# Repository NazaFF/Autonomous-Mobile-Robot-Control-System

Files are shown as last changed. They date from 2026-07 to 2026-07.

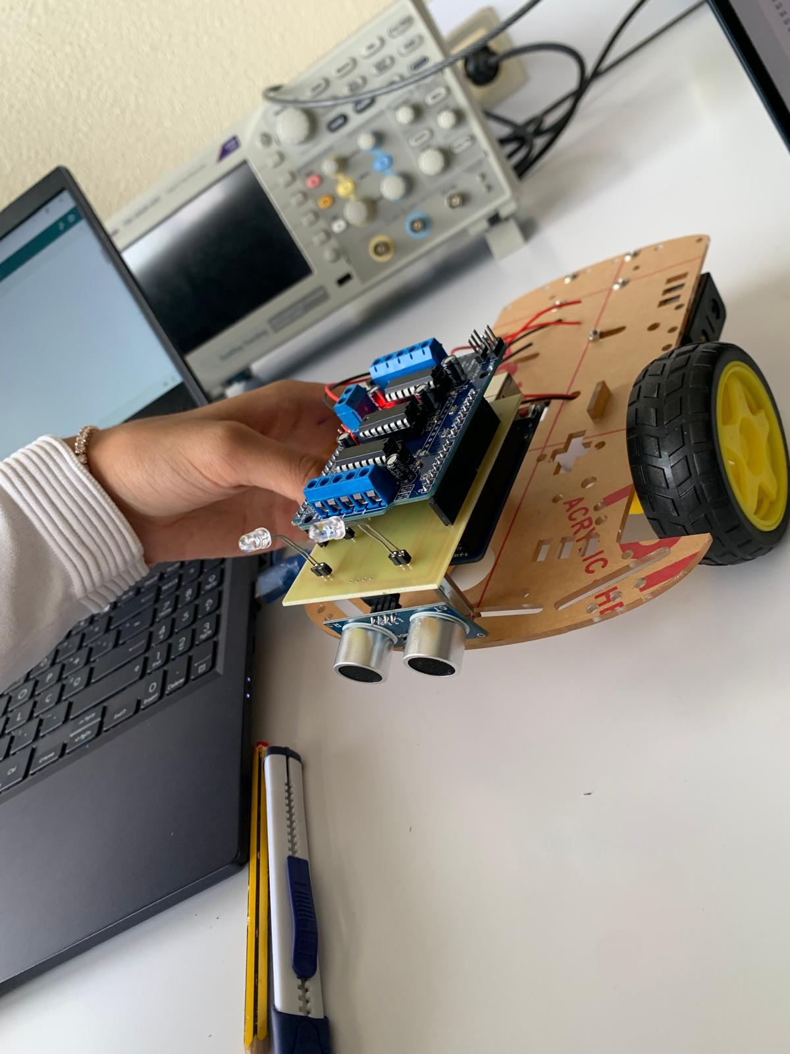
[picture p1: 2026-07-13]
Images/Robot/Robo_1.jpg

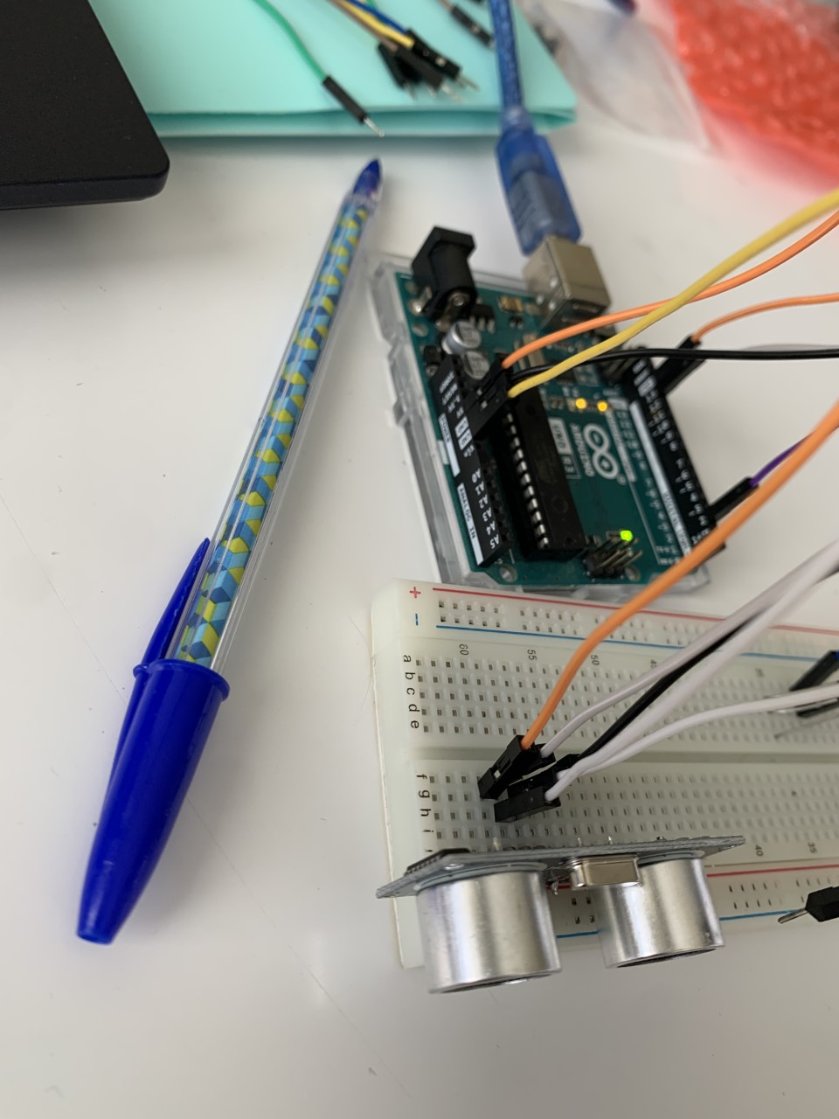
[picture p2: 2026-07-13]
Images/BreadBoard/Placa_3.jpg

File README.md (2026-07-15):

# Autonomous-Mobile-Robot-Control-System
Embedded mobile robotic platform featuring autonomous navigation, obstacle avoidance, light tracking and infrared remote control.







---

# Project Overview

This project presents the design and development of an embedded mobile robotic platform capable of operating in both manual and autonomous modes.

The robot integrates multiple sensing technologies and embedded control algorithms to perform autonomous navigation, obstacle avoidance and light source tracking while also supporting wireless infrared remote control.

The project was developed following a complete engineering workflow, from circuit prototyping and firmware development to PCB design, assembly and system integration.

---

# Project Objectives

- Design a fully functional embedded robotic platform
- Develop a custom PCB
- Integrate multiple sensing technologies
- Implement autonomous navigation algorithms
- Develop wireless infrared remote control
- Implement obstacle avoidance
- Implement light tracking
- Integrate hardware and embedded software

---

# Main Features

- Autonomous obstacle avoidance
- Light source tracking
- Wireless infrared remote control
- DC motor control
- Embedded decision logic
- Real-time sensor acquisition
- Custom PCB
- Arduino-based embedded firmware
- Modular software architecture

---

# Development Process

The project followed an iterative engineering development process.

## Phase 1 — Initial Prototype

The first version was assembled on a breadboard to validate:

- Motor control
- Infrared communication
- Ultrasonic sensor
- Light sensors
- Embedded firmware

📷 **Breadboard Prototype** 

Placa_1

---

## Phase 2 — PCB Design

After validating the prototype, a custom PCB was designed using Autodesk Eagle.

The PCB integrates all sensors, connectors and control electronics required by the robot.

📷 **PCB Schematic**

Esquema_SCH_final

📷 **PCB Layout**

BRD_final

---

## Phase 3 — PCB Assembly

The PCB was manufactured and assembled by soldering all electronic components.

The board was then integrated into the mobile robot chassis.

📷 **PCB Assembly Image**



---

## Phase 4 — Final Robot

The completed platform integrates:

- Arduino
- Motor Driver
- Infrared Receiver
- Ultrasonic Sensor
- Light Sensors
- Custom PCB
- DC Motors
- Battery Pack

📷 **Robot Image**

Robo_2

---

# Hardware

| Component | Purpose |
|---|---|
| Arduino | Main controller |
| DC Motors | Robot locomotion |
| Motor Shield | Motor control |
| Ultrasonic Sensor | Obstacle detection |
| Infrared Receiver | Wireless remote control |
| Photodiodes | Light tracking |
| Custom PCB | Hardware integration |
| Battery Pack | Power supply |

---

# Software

- Arduino IDE
- C++
- Embedded Programming
- Motor Control
- Sensor Processing
- Decision Logic

---

# System Architecture

```text
                  Infrared Remote
                         │
                         ▼
                 Infrared Receiver
                         │
                         ▼
                 Arduino Controller
                         │
       ┌─────────────────┼─────────────────┐
       │                 │                 │
       ▼                 ▼                 ▼
Ultrasonic Sensor   Light Sensors    Motor Driver
       │                                   │
       └─────────────────┬─────────────────┘
                         ▼
                     DC Motors
                         │
                         ▼
                  Mobile Robot Motion
```

---

# Robot Operating Modes

## Manual Mode

The robot is controlled using an infrared remote controller.

The user can:

- Move forward
- Move backward
- Turn left
- Turn right
- Stop

---

## Autonomous Mode

The robot continuously measures the surrounding environment using the ultrasonic sensor.

When an obstacle is detected, the embedded control algorithm selects a new direction to avoid collisions.

---

## Light Tracking Mode

The robot uses two photodiodes to detect the direction of a light source.

The embedded firmware compares both sensor readings and adjusts the robot trajectory accordingly.

---

# Software Architecture

The firmware is organised into multiple functional modules:

- Motor Control
- Obstacle Detection
- Light Tracking
- Infrared Communication
- Robot Motion
- Decision Logic

---

# PCB Design

A dedicated PCB was designed using Autodesk Eagle to improve:

- Reliability
- Mechanical robustness
- Wiring organization
- Ease of assembly

📷 **Eagle Schematic**

Esquema_SCH_final

📷 **PCB Routing**

BRD_final

---

# Results

The final platform successfully demonstrates:

- Autonomous navigation
- Wireless robot control
- Obstacle avoidance
- Light source tracking
- Embedded software integration
- PCB design and assembly
- Hardware/software integration

---

# Engineering Skills Demonstrated

- Embedded Systems
- Mobile Robotics
- Arduino Programming
- PCB Design
- Schematic Design
- Sensor Integration
- Infrared Communication
- Motor Control
- Embedded Debugging
- Electronics Assembly
- Hardware Integration
- Autonomous Navigation

---

# Challenges

Several engineering challenges were encountered during development:

- Sensor calibration
- Noise filtering
- Infrared communication reliability
- Motor synchronization
- PCB debugging
- Embedded software integration

These challenges were progressively solved through testing, debugging and iterative hardware improvements.

---

# Future Improvements

Possible future developments include:

- Bluetooth control
- Wi-Fi communication
- PID motor control
- Wheel encoders
- Closed-loop navigation
- SLAM algorithms
- Camera vision
- Object detection
- ROS integration

---

# License

This project is licensed under the MIT License.

---

# Author's

**Tomás Ferreira**
**Adriana Pires**

Electrical & Telecommunications Engineers

**Areas of Interest**

- Industrial Automation
- Embedded Systems
- Robotics
- Industrial Electronics
- Control Engineering
- Industry 4.0

Feel free to explore my other engineering projects and connect with me on LinkedIn.

## Contact
- Email: ferreiratomas994@gmail.com
- Outlkook tomasff52@ua.pt
- LinkedIn: (https://www.linkedin.com/in/tomas-ferreira-52635a2b8/?isSelfProfile=true)

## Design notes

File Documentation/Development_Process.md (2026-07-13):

# Development Process

This project followed an iterative engineering development methodology.

---

# 1. Requirements Definition

The objective was to design an embedded mobile robotic platform capable of operating both autonomously and under wireless remote control.

The robot should:

- Navigate safely
- Avoid obstacles
- Track a light source
- Support manual operation
- Integrate multiple sensors
- Be implemented on a custom PCB

---

# 2. Electronics Prototyping

All electronic subsystems were initially validated on a breadboard.

Subsystems tested:

- DC motors
- Motor driver
- Ultrasonic sensor
- Infrared receiver
- Light sensors

📷 Insert Breadboard Image

---

# 3. Embedded Software Development

Each subsystem was individually validated before system integration.

Examples include:

- Motor control
- Distance measurement
- Infrared communication
- Light sensor acquisition

The software was progressively integrated into a single firmware.

---

# 4. PCB Design

After validating the prototype, a dedicated PCB was designed using Autodesk Eagle.

Design goals included:

- Compact layout
- Improved reliability
- Easier assembly
- Reduced wiring complexity

📷 Insert Eagle Schematic

📷 Insert PCB Layout

---

# 5. PCB Assembly

The manufactured PCB was assembled and tested before integration into the robotic platform.

📷 Insert PCB Assembly

---

# 6. Robot Integration

All hardware modules were integrated into the robot chassis.

Integrated modules include:

- Arduino
- Motor Shield
- Custom PCB
- Ultrasonic sensor
- Infrared receiver
- Light sensors
- DC motors

📷 Insert Final Robot

---

# 7. System Validation

The final prototype was tested under different operating modes.

## Manual Mode

Wireless infrared control.

---

## Obstacle Avoidance

Autonomous navigation using ultrasonic sensing.

---

## Light Tracking

Automatic movement towards a light source.

---

# Engineering Skills Demonstrated

- Embedded Systems
- Robotics
- PCB Design
- Hardware Integration
- Embedded Programming
- Sensor Integration
- Motor Control
- Electronics Prototyping
- Embedded Debugging
- System Validation

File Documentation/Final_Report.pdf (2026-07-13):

## Departamento de Eletrónica e Telecomunicações e In-

## formática

# Relatório

Autor: Adriana Pires

Autor: Tomás Ferreira

Data: 13/06/2023

Resumo:
O projeto visa integração de três tipos de sensores num robô, utilizando a plataforma Arduino e o shield dos motores.

Índice:

1.Introdução

### 1.1 Objetivo

### 1.2 Enquadramento

### 1.3 Metodologia utilizada

2.Placa de circuito impresso (PCB)

### 2.1 Etapas de desenvolvimento

### 2.2 Problemas encontrados/Soluções

3.Placa branca

### 3.1 Componentes utilizados

### 3.1.1 Descrição dos componentes utilizados

### 3.1.2 Solução Hardware

### 3.1.3 Desenvolvimento do Software

### 3.2 Testes dos circuitos

4.Robo

### 4.1 Descrição do robô utilizado

### 4.2 Solução Hardware

### 4.3 Programação do robô

5.Procedimento/Descrição

6.Resultados

7.Conclusões

8.Webgrafia e Bibliografia

### 1. Introdução

### 1.1 Objetivo:

Este projeto tem como objetivo a consolidação e aplicação dos conhecimentos adquiridos, bem como a criação de métodos de trabalho e organização.
Um dos objetivos também deste projeto, é desenvolver um módulo de interação entre o utilizador humano e o robô usando um comando remoto por infravermelhos (IV). Esta é uma forma simples de transferência de dados sem fios.

### 1.2 Enquadramento:

Pretende-se controlar o comportamento do robô com recurso a diversos sensores e adotando a plataforma Arduino como unidade inteligente e programável.

Em primeiro lugar, pretende-se desenvolver um sensor de luminosidade, baseado em foto-díodos, que permita ao robô detetar e seguir uma fonte luminosa.

Em segundo lugar, pretende-se usar um sensor capaz de medir distâncias, baseado em ultrassons, para dotar o robô de capacidade para detetar e evitar obstáculos presentes no ambiente.

Finalmente, pretende-se interagir com o robô através de um comando remoto por infravermelhos.

O trabalho proposto pressupõe a integração dos diversos módulos hardware e a programação do robô móvel tendo em vista o controlo dos seus movimentos de forma versátil e segura.

### 1.3 Metodologia utilizada:

Com o objetivo do projeto já definido, e com um estudo prévio sobre o tema, foi possível analisar as características dos módulos e assim, avaliar capacidades, limitações e criar uma solução para os problemas detetados.

Etapas:

-Montagem do circuito em placa branca;

-Desenvolvimento do código;

-Teste dos códigos de ligação ao Arduino;

-Desenvolvimento do modulo integrado (Shield);

-Soldar componentes;

-Verificação dos códigos de ligação ao Arduino+PCB;

-Testes com robô;

-Verificação do desempenho do projeto;

2.Placa de circuito impresso (PCB)

### 2.1 Etapas de desenvolvimento:

Em primeiro lugar analisamos o esquemático fornecido pelo docente, depois passamos à elaboração da board a partir desse mesmo esquemático, tendo sempre em consideração a disposição dos componentes. Na parte final, soldamos o PCB mas sempre atendendo as regras para soldar.

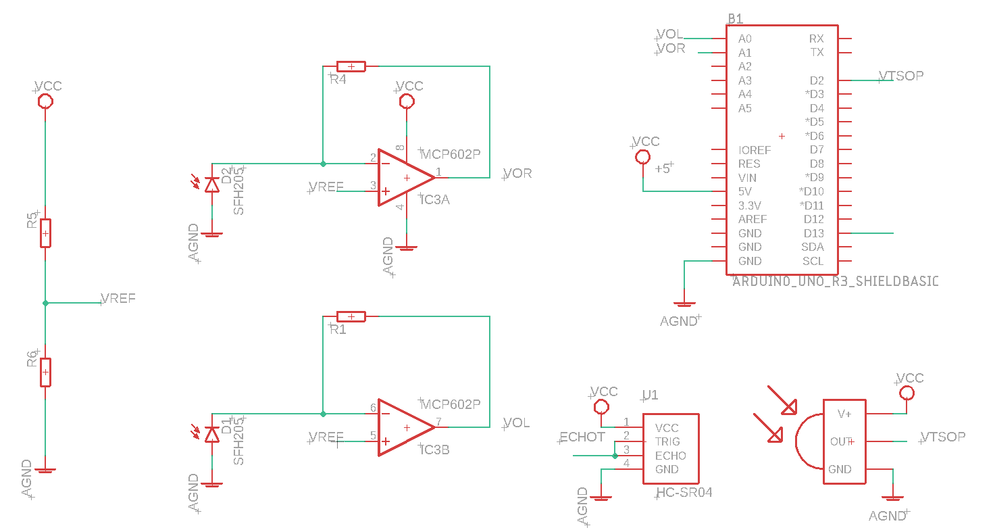
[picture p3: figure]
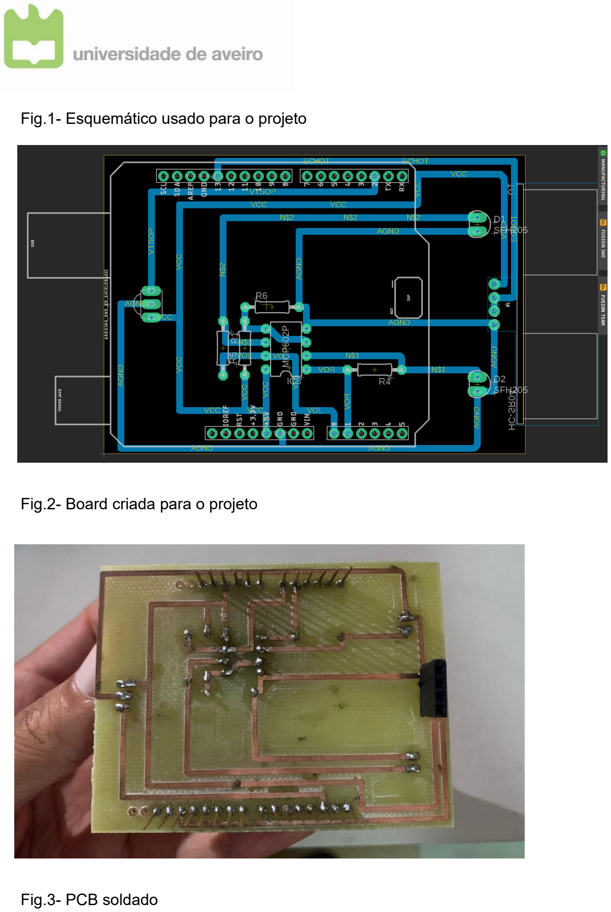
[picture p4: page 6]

Fig.1- Esquemático usado para o projeto

Fig.2- Board criada para o projeto

Fig.3- PCB soldado

### 2.2 Problemas encontrados/Soluções:

Na solução da board, para além da configuração especifica que tivemos de respeitar, tivemos a preocupação de fazer linhas perpendiculares, atendendo ao método fabrico da placa.

Também tivemos em consideração a disposição dos componentes e que nenhuma pista se cruzasse e ao mesmo tempo uma posição lógica dos componentes no circuito da placa.

Quando soldamos o PCB, tivemos de ter cuidado com a temperatura do ferro para não danificar os componentes e pistas, mas que permitisse uma soldadura correcta. Também houve a preocupação para que a solda não passasse para os pinos e pistas próximas.

### 3. Placa branca

### 3.1 Componentes utilizados:

### 3.1.1 Descrição dos componentes utilizados:

O funcionamento do sensor de luminosidade baseia-se no facto da corrente num foto-díodo inversamente polarizado ser proporcional à intensidade luminosa que atinge a sua área sensível, permitindo a transdução da intensidade luminosa numa grandeza

2 Foto-díodos

Resistencia 1kΩ

Resistencia 10 kΩ

2 Resistências 100 kΩ

Integrado (MCP602)

Sensor de distância HC-SR04

Recetor TSOP582 elétrica, ou seja, o foto-díodo é um dispositivo semicondutor que converte luz em corrente elétrica.

https://docs.rs-online.com/f594/0900766b814f568d.pdf : link para o datasheet do foto-díodo SFH213.

Para a implementação do circuito com os foto-díodos foi também utilizado um AmpOp MCP601, segue de seguida o link para o seu datasheet:

https://docs.rs-online.com/1dfa/0900766b8166f966.pdf

A medição de distâncias por ultrassons baseia-se na emissão de uma sequência de impulsos e na subsequente leitura do eco, ou seja, este método de determinação da distância de um objeto baseia-se no intervalo de tempo entre a emissão do sinal ultrassônico pelo emissor e o retorno do sinal refletido pelo objeto.

O tempo decorrido entre a emissão do sinal e a receção do correspondente eco está relacionado com a distância ao objeto que causou o eco.

Como é possível de comprovar, mais abaixo, através da visualização da onda obtida no osciloscópio (Fig.8, Fig.9, Fig.10), ou seja, é possível verificar que quando mais largo o impulso maior é a distancia do emissor ao obstáculo.

https://cdn.sparkfun.com/datasheets/Sensors/Proximity/HCSR04.pdf : Link para o datasheet do sensor de distância HC-SR04.

O circuito associado ao comando remoto por infravermelhos será baseado no recetor TSOP582 que faz a descodificação do sinal recebido. O circuito integrado TSOP582 gera um sinal digital na saída (OUT) que poderá ser lido por um microcontrolador

https://www.vishay.com/docs/82491/tsop382.pdf : Link para o datasheet do recetor TSOP.

### 3.1.2 Solução Hardware:

-Foto-díodos:

Como Vref. tomamos o valor de 0,45V e assim através de um divisor de tensão chegamos ao valor das duas resistências (ilustradas na figura seguinte como R1 e R2).

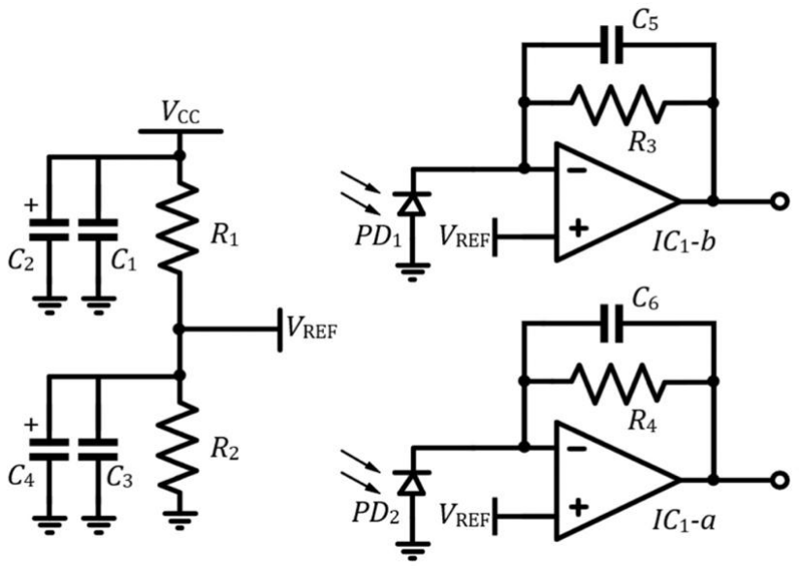
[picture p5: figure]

Fig.4- Esquemático completo do circuito sensor de luz

Como VCC é igual a 5V e Vref. é igual a 0,45V, então pela fórmula do divisor de tensão R1=10kΩ e R2 =1kΩ (no esquemático, estas resistências correspondem, respetivamente, a R5 e R6).

## Vref =

R2
R2 + R1

## ∗ Vcc

0,45 =

R2
R2+R1

∗ 5

## R1=10kΩ e R2 =1kΩ

Já R3 e R4 (no esquemático, estas resistências correspondem, respetivamente, a R1 e R4), decidimos experimentalmente que iria ser de 100kΩ, porque ao usar a luz do telemóvel foi obtido uma maior variação.

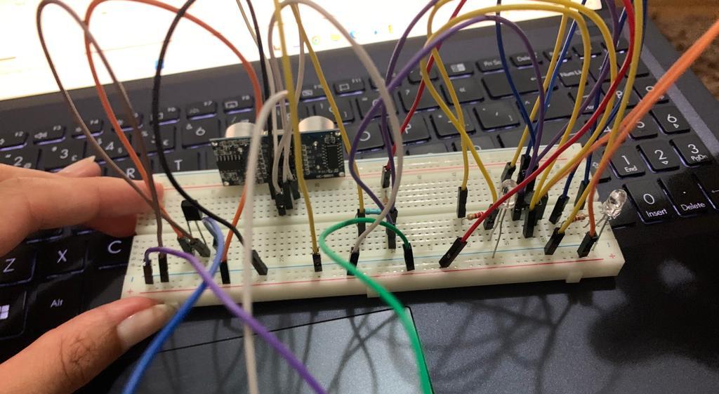
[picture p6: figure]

Nesta foto não é muito visível a disposição dos componentes, mas foi assim que ficou a nossa placa usada para testes.

Fig.5- Circuito completo na placa branca

### 3.1.3 Desenvolvimento Software:

Antes de implementarmos o código com todos os módulos, testamos em separado cada um usando os seguintes códigos:

-Foto-díodos:

void setup() {

Serial.begin(9600);

}

void loop() {
int ValueL = analogRead(A0); int ValueR = analogRead(A1); int NormalLight=285;

float vL =(ValueL) ;
Serial.print("esq: ");
Serial.print(vL);
float vR =(ValueR) ;
Serial.print(" | dir: ");
Serial.print(vR);

Serial.print("**");
Serial.print(vR-vL);
Serial.print("**");

if((vR+vL)>NormalLight &&(vR-vL)>5) Serial.println("-> Turn Right...");
else if((vR+vL)>NormalLight &&(vR-vL)<-5) Serial.println("-> Turn Left...");
else if ((vR+vL)>NormalLight && abs(vR-vL)<5) Serial.println("-> In front...");
else
Serial.println("-> Search for light..."); delay(800);

}

-Ultrassom:

// ---------------------------------------------------------------------------// Example NewPing library sketch that does a ping about 20 times per second.

// ---------------------------------------------------------------------------

#include <NewPing.h>

#define TRIGGER_PIN 13 // Arduino pin tied to trigger pin on the ultrasonic sensor.

#define ECHO_PIN | 13 | // Arduino pin tied to echo pin on the ultrasonic sensor.

#define MAX_DISTANCE 200 // Maximum distance we want to ping for (in centimeters). Maximum sensor distance is rated at 400-500cm.

NewPing sonar(TRIGGER_PIN, ECHO_PIN, MAX_DISTANCE); // NewPing setup of pins and maximum distance.

void setup() {
Serial.begin(9600); | | // Open serial monitor at 115200 baud to see ping results.
}

void loop() {
delay(50); | | // Wait 50ms between pings (about 20 pings/sec).
29ms should be the shortest delay between pings.
Serial.print("Ping: ");
Serial.print(sonar.ping_cm()); // Send ping, get distance in cm and print result (0 = outside set distance range)
Serial.println("cm");
}

-Comando:
// Arduino NEC Protocol IR remote control decoder #define MOVE_FORWARD 136

char text[5];
boolean nec_ok = 0;
byte i, nec_state = 0, command, inv_command; unsigned int address;
unsigned long nec_code;

void setup() {
Serial.begin(9600);
Serial.println("Acabadinho de entrar...");
// Timer1 module configuration
TCCR1A = 0;
TCCR1B = 0; | | // Disable Timer1 module

TCNT1 = 0; | // Set Timer1 preload value to 0
(reset)
TIMSK1 = 1; | // enable Timer1 overflow inter-
rupt
attachInterrupt(digitalPinToInterrupt(2), remote_read, CHANGE); | // Enable
external interrupt (INT0)
}

void loop() {
// Read the remote command
if(nec_ok){
// If the mcu receives NEC message with successful
nec_ok = 0; | // Reset decoding process
nec_state = 0;
TCCR1B = 0; | // Disable Timer1 module
// Define: address = nec_code >> 16;
command = nec_code >> 8; | // Define: inv_command = nec_code;
Serial.print("Command: ");
Serial.println(command);
attachInterrupt(0, remote_read, CHANGE); // Enable external interrupt (INT0)
}
// Read the US-distance sensor (HC-SR04)

// Read the light sensor (photodiodes)

// Update the robot's behavior
if (command == MOVE_FORWARD)
Serial.println("Go to MOVE_FORWARD routine");
}

Com o seguinte código auxiliar:
void remote_read() {
unsigned int timer_value;
if(nec_state != 0){
timer_value = TCNT1; | // Store Timer1 value
TCNT1 = 0; | // Reset Timer1
}
switch(nec_state){

case 0 : | // Start receiving IR data (we're
at the beginning of 9ms pulse)
TCNT1 = 0; | // Reset Timer1
TCCR1B = 2; | // Enable Timer1 module with 1/8
prescaler ( 2 ticks every 1 us)
nec_state = 1; | // Next state: end of 9ms pulse
(start of 4.5ms space)
i = 0;
return;
case 1 : | // End of 9ms pulse
//Serial.println("SLB simply the best1");
if((timer_value > 19000) || (timer_value < 17000)){ | // Invalid interval
==> stop decoding and reset
nec_state = 0; | // Reset decoding process
TCCR1B = 0; | // Disable Timer1 module
}
else
nec_state = 2; | // Next state: end of 4.5ms space
(start of 562µs pulse)
return;
case 2 : | // End of 4.5ms space
if((timer_value > 10000) || (timer_value < 8000)){
nec_state = 0; | // Reset decoding process
TCCR1B = 0; | // Disable Timer1 module
}
else
nec_state = 3; | // Next state: end of 562µs pulse
(start of 562µs or 1687µs space)
return;
case 3 : | // End of 562µs pulse
//Serial.println("SLB simply the best");
if((timer_value > 1400) || (timer_value < 800)){ | // Invalid interval
==> stop decoding and reset
TCCR1B = 0; | // Disable Timer1 module
nec_state = 0; | // Reset decoding process
}
else
nec_state = 4; | // Next state: end of 562µs or
1687µs space
return;
case 4 : | // End of 562µs or 1687µs space
if((timer_value > 3600) || (timer_value < 800)){ | // Time interval in-
valid ==> stop decoding
TCCR1B = 0; | // Disable Timer1 module
nec_state = 0; | // Reset decoding process
return;

}
if( timer_value > 2000) | // If space width > 1ms (short
space)
bitSet(nec_code, (31 - i)); | // Write 1 to bit (31 - i)
else | // If space width < 1ms (long
space)
bitClear(nec_code, (31 - i)); | // Write 0 to bit (31 - i)
i++;
//Serial.print(i);
if(i > 31){ | // If all bits are received
//Serial.print("NumBitsRec=");
nec_ok = 1; | // Decoding process OK
detachInterrupt(0); | // Disable external interrupt
(INT0)
return;
}
nec_state = 3; | // Next state: end of 562µs pulse
(start of 562µs or 1687µs space)
}
}
ISR(TIMER1_OVF_vect) { | // Timer1 interrupt service rou-
tine (ISR)
nec_state = 0; | // Reset decoding process
TCCR1B = 0; | // Disable Timer1 module
}

### 3.2 Testes dos circuitos:

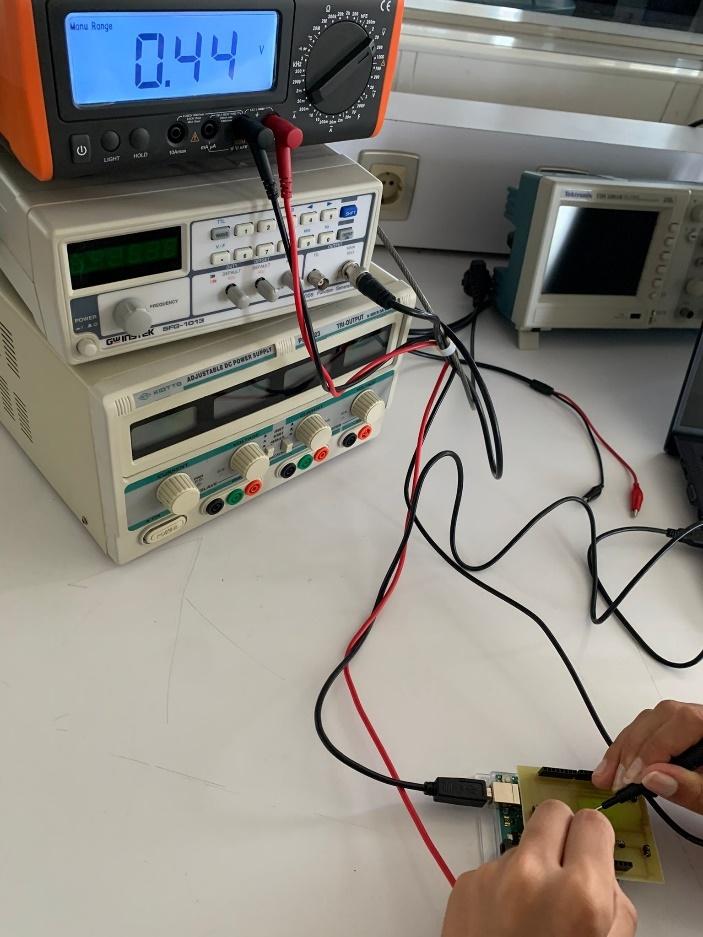
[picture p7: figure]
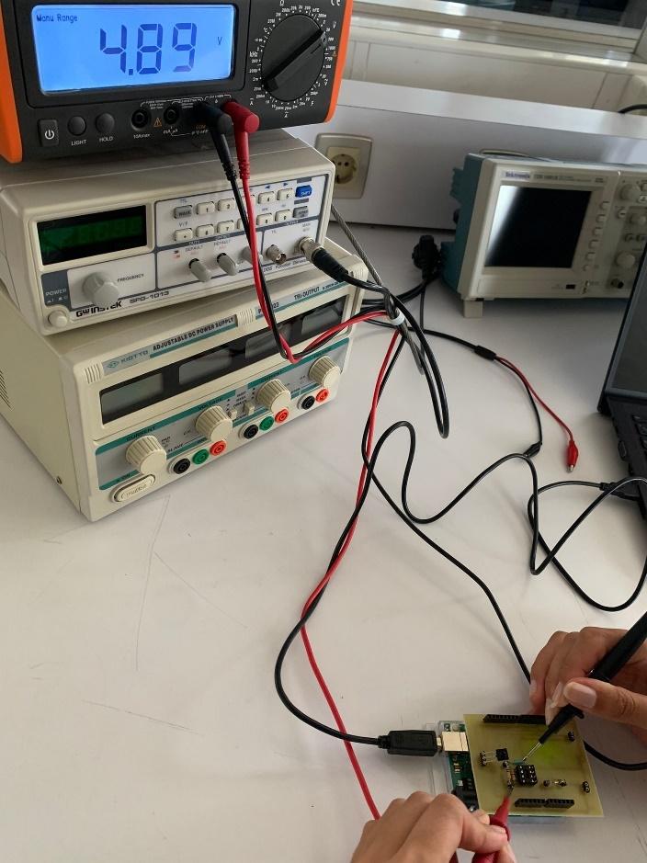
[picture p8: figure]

Fig.6 –Valor pratico de Vcc(valor teórico =5,0V) | Fig.7 – Valor pratico de Vref (valor teórico =0,45V)

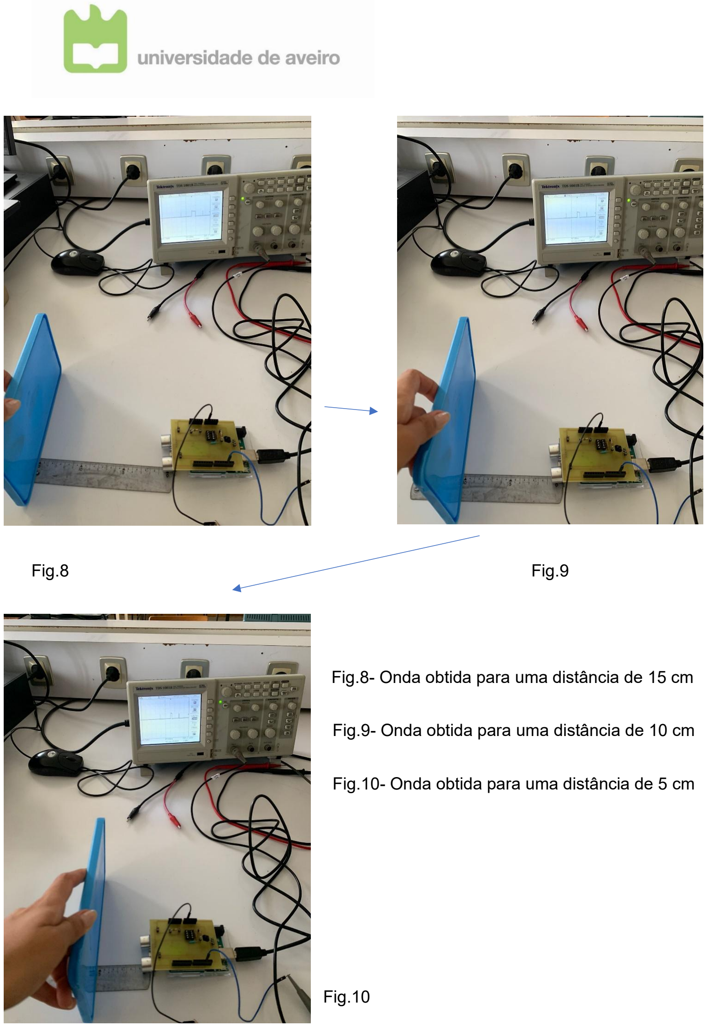
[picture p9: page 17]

Fig.8 | Fig.9

Fig.8- Onda obtida para uma distância de 15 cm

Fig.9- Onda obtida para uma distância de 10 cm

Fig.10- Onda obtida para uma distância de 5 cm

Fig.10

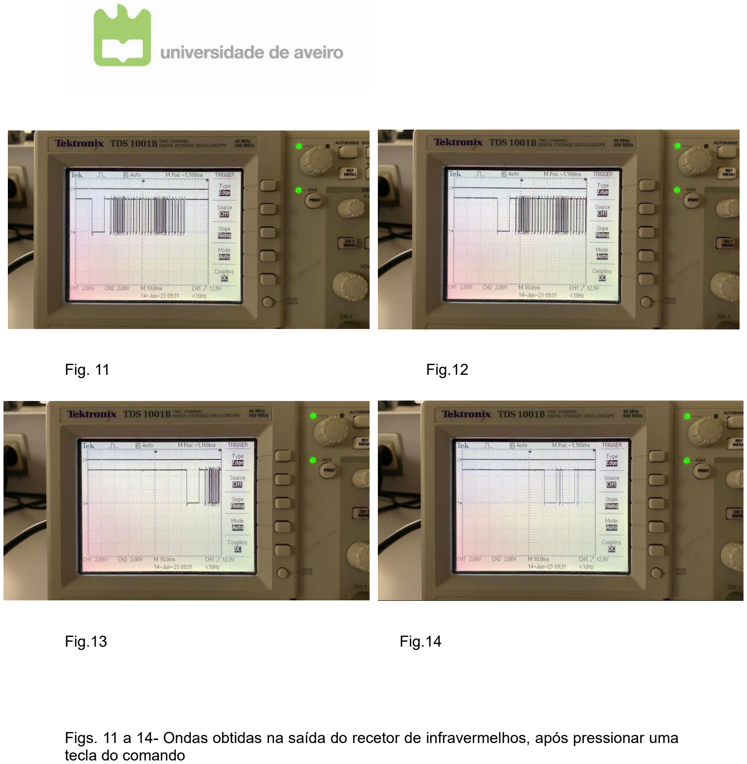
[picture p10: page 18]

Fig. 11 | Fig.12
Fig.13 | Fig.14

Figs. 11 a 14- Ondas obtidas na saída do recetor de infravermelhos, após pressionar uma tecla do comando

### 4. Robô

### 4.1 Descrição do robô utilizado:

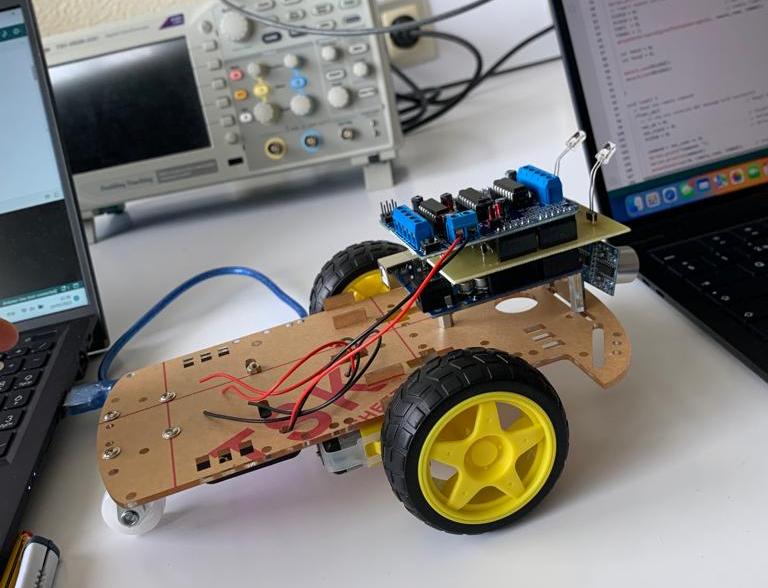
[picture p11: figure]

Fig.15- Montagem do robô com todos os módulos

### 4.2 Solução Hardware:

// Arduino NEC Protocol IR remote control decoder

#include <NewPing.h>

char text[5];
boolean nec_ok = 0;
byte i, nec_state = 0, command, inv_command; unsigned int address;
unsigned long nec_code;
unsigned long distancia;

int type_mov =0; //se estado é detetar obstaculos(2) ou luz(1) boolean mov = false; //se esta a andar ou parado

//MOTORES
#include <AFMotor.h>

AF_DCMotor motor1 (1);
AF_DCMotor motor2 (2);

//SL
float vL,vR, NormalLight=100; | //Nivel luz ambiente
#define dL A0

#define dR A1

//US
#define TRIGGER_PIN 13 // Arduino pin tied to trigger pin on the ultrasonic sensor.

#define ECHO_PIN | 13 | // Arduino pin tied to echo pin on the ultrasonic sensor.

#define MAX_DISTANCE 400 // Maximum distance we want to ping for (in centimeters). Maximum sensor distance is rated at 400-500cm.

#define command_front 8 //2

#define command_back 104 //8

#define command_right 40 //6

#define command_left 72 //4

#define command_menu 4 //TXT #define command_startstop 64 //vermelho

#define command_searchlight 144 | //1

#define command_us 136 | //3

#define command_stop 152 | //0

NewPing sonar(TRIGGER_PIN, ECHO_PIN, MAX_DISTANCE); // NewPing setup of pins and maximum distance.

//FUNÇÕES-----------
int velocidade=80; | //Velocidade por defeito

//IR EM FRENTE
void Front(int velocidade){ //os dois motores tem que arrancar e entra a velocidade Serial.println("Front ..... ");
motor1.run(FORWARD);
motor2.run(FORWARD);

motor1.setSpeed(velocidade); motor2.setSpeed(velocidade);

}

//ANDAR PARA TRAS
void Back(int velocidade){ //os dois motores tem que arrancar e entra a velocidade Serial.print("Back ..... ");
motor1.run(BACKWARD);
motor2.run(BACKWARD);

motor1.setSpeed(velocidade); motor2.setSpeed(velocidade);

}

//TURN RIGHT
void TurnRight(int velocidade){ //RODAR PARA A DIREITA

Serial.println("Turn Right ..... ");

motor1.run(BACKWARD); // Motor 1 anda no sentido inverso do motor 2 motor2.run(FORWARD); // Girar robo para a direita

motor1.setSpeed(velocidade);
motor2.setSpeed(velocidade);
}

//TURN LEFT
void TurnLeft(int velocidade){ //RODAR PARA A ESQUERDA

Serial.println("Turn Left ..... ");

motor1.run(FORWARD); // Motor 1 anda no sentido inverso do motor 2 motor2.run(BACKWARD); // Girar robo para a esquerda

motor1.setSpeed(velocidade);

motor2.setSpeed(velocidade);

}

//PARAR
void STOP(){
motor1.run(RELEASE);
motor2.run(RELEASE);
Serial.println("STOP ..... "); }

//PROCURAR LUZ

void SearchLight(int velocidade, int NormalLight){ //se encontrar osbstaculos para, se nao segue em frente ou procura luz
vL = analogRead(dL);
vR = analogRead(dR);
Serial.print("SearchLight ..... "); if((vR+vL)>NormalLight &&(vR-vL)<-5){ if(sonar.ping_cm()< 10 ){
Back(50);
}
else
TurnLeft(velocidade);

}
else if((vR+vL)>NormalLight &&(vR-vL)>5){

if(sonar.ping_cm()< 10 ){
Back(50);
}
else
TurnRight(velocidade);

}
else if ((vR+vL)>NormalLight && abs(vR-vL)<=5){ if(sonar.ping_cm()<10){
Back(50);
}
else
Front(sonar.ping_cm());

}
else
Girar();

}

//RODAR SOBRE SI PROPRIO
void Girar(){

motor1.run(FORWARD); // Girar motor3 para a esquerda motor2.run(BACKWARD); // Motor 1 anda no sentido inverso do motor 2 motor1.setSpeed(velocidade);
motor2.setSpeed(velocidade);
Serial.println("Girar..... ");
if(sonar.ping_cm() <10){
Back(50);
}
}

//EVITAR OBSTÁCULOS
void DetectObstacles(int min_dist){
if(sonar.ping_cm() >= min_dist) //se ele se encontrar a menos de 10 cm do obsta-culo para
Front(sonar.ping_cm());
else
Girar();
Serial.print("Detects Obstacles ..... ");

}

int ReadCommnand(){ // Function Read the remote command
if(nec_ok){
// If the mcu receives NEC message with successful
nec_ok = 0; | // Reset decoding process
nec_state = 0;
TCCR1B = 0; | // Disable Timer1 module
// Define: address = nec_code >> 16;
command = nec_code >> 8; | // Define: inv_command = nec_code;
Serial.print("Command: ");
Serial.println(command);
attachInterrupt(0, remote_read, CHANGE); // Enable external interrupt (INT0)
}
return command;
}

void selectmenu(){

Serial.println(" ");

Serial.println(" ");
Serial.println("**SELECT MENU ***"); Serial.println("Arranque/Paragem, Press (start red)"); Serial.println("Front, Press 2 "); Serial.println("Back, Press 8 "); Serial.println("Turn Left, Press 4 "); Serial.println("Turn Right, Press 6 "); Serial.println("Stop, Press 0)"); Serial.println("For light search, Press 1 "); Serial.println("For obstacles deviation, Press 3 "); Serial.println("For comand intruction, Press TXT ");

}

void setup() {

Serial.begin(9600);
Serial.println("Acabadinho de entrar...");
// Timer1 module configuration
TCCR1A = 0;
TCCR1B = 0; | // Disable Timer1 module
TCNT1 = 0; | // Set Timer1 preload value to 0
(reset)
TIMSK1 = 1; | // enable Timer1 overflow inter-
rupt
attachInterrupt(digitalPinToInterrupt(2), remote_read, CHANGE); | // Enable
external interrupt (INT0)

}

void loop() {

// Read the remote command
if(nec_ok){
// If the mcu receives NEC message with successful
nec_ok = 0; | // Reset decoding process
nec_state = 0;
TCCR1B = 0; | // Disable Timer1 module
| // Define: address = nec_code >>
16;
command = nec_code >> 8; | // Define: inv_command = nec_code;
Serial.print("Command: ");
Serial.println(command);
attachInterrupt(0, remote_read, CHANGE); // Enable external interrupt (INT0)
}

delay(50); | // Wait 50ms between pings (about 20 pings/sec).
29ms should be the shortest delay between pings.
Serial.print("Ping: ");
Serial.print(sonar.ping_cm()); // Send ping, get distance in cm and print result (0 = outside set distance range)
Serial.println("cm"); //AJUSTAR
// Serial.println((sonar.ping_cm()-3)*(sonar.ping_cm()-3));

// Read the light sensor (photodiodes)
vL = analogRead(dL);
vR = analogRead(dR);
Serial.print("Light Left: "); Serial.print(vL);
Serial.print(" | Light Right: ");
Serial.println(vR);

if (command ==command_menu ){ //colocar codigo comando correspondente à tecla menu selectmenu();
do{
command= ReadCommnand();
}while (!nec_ok);
}

if(command == command_front ){ Front(velocidade);

}

if(command == command_back ){ Back(velocidade);

}

if(command == command_right ){ TurnRight(velocidade);

}

if(command == command_left ){ TurnLeft(velocidade);

}

if(command == command_stop ){ STOP();

mov = false;

}

if (command == command_searchlight ){ SearchLight(velocidade, NormalLight); type_mov=1;
mov = true;

}

if (command == command_us ){ DetectObstacles(5);
type_mov =2;
mov=true;

}
if(command == command_startstop){ if( mov){
STOP();

mov = false;
command=0;
}
else{
if(type_mov ==1){
SearchLight(velocidade, NormalLight); mov=true;
command=0;

}
if(type_mov ==2)
DetectObstacles(5);
mov=true;
command=0;
}

}
delay(1000);

}

Com o seguinte código auxiliar:

void remote_read() {
unsigned int timer_value;

if(nec_state != 0){
timer_value = TCNT1; | // Store Timer1 value
TCNT1 = 0; | // Reset Timer1
}
switch(nec_state){
case 0 : | // Start receiving IR data (we're
at the beginning of 9ms pulse)
TCNT1 = 0; | // Reset Timer1
TCCR1B = 2; | // Enable Timer1 module with 1/8
prescaler ( 2 ticks every 1 us)
nec_state = 1; | // Next state: end of 9ms pulse
(start of 4.5ms space)
i = 0;
return;
case 1 : | // End of 9ms pulse
//Serial.println("SLB simply the best1");
if((timer_value > 19000) || (timer_value < 17000)){ | // Invalid interval
==> stop decoding and reset
nec_state = 0; | // Reset decoding process
TCCR1B = 0; | // Disable Timer1 module
}
else
nec_state = 2; | // Next state: end of 4.5ms space
(start of 562µs pulse)
return;
case 2 : | // End of 4.5ms space
if((timer_value > 10000) || (timer_value < 8000)){
nec_state = 0; | // Reset decoding process
TCCR1B = 0; | // Disable Timer1 module
}
else
nec_state = 3; | // Next state: end of 562µs pulse
(start of 562µs or 1687µs space)
return;
case 3 : | // End of 562µs pulse
//Serial.println("SLB simply the best");
if((timer_value > 1400) || (timer_value < 800)){ | // Invalid interval
==> stop decoding and reset
TCCR1B = 0; | // Disable Timer1 module
nec_state = 0; | // Reset decoding process
}
else
nec_state = 4; | // Next state: end of 562µs or
1687µs space
return;
case 4 : | // End of 562µs or 1687µs space

if((timer_value > 3600) || (timer_value < 800)){ | // Time interval in-
valid ==> stop decoding
TCCR1B = 0; | // Disable Timer1 module
nec_state = 0; | // Reset decoding process
return;
}
if( timer_value > 2000) | // If space width > 1ms (short
space)
bitSet(nec_code, (31 - i)); | // Write 1 to bit (31 - i)
else | // If space width < 1ms (long
space)
bitClear(nec_code, (31 - i)); | // Write 0 to bit (31 - i)
i++;
//Serial.print(i);
if(i > 31){ | // If all bits are received
//Serial.print("NumBitsRec=");
nec_ok = 1; | // Decoding process OK
detachInterrupt(0); | // Disable external interrupt
(INT0)
return;
}
nec_state = 3; | // Next state: end of 562µs pulse
(start of 562µs or 1687µs space)
}
}
ISR(TIMER1_OVF_vect) { | // Timer1 interrupt service rou-
tine (ISR)
nec_state = 0; | // Reset decoding process
TCCR1B = 0; | // Disable Timer1 module
}

### 4.3 Programação do robô:

Decidimos implementar um menu para o utilizador ter conhecimento das funções existentes.

Menu:

Arranque/Paragem: tecla Start_Stop

Front | : tecla 2
Back | : tecla 8
Turn Left | : tecla 4
Turn Right | : tecla 6
Search Light | : tecla 1
Obstáculos | : tecla 3
Menu | : tecla TXT

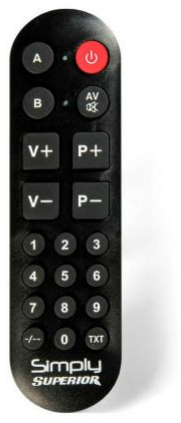
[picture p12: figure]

Fig.16- Comando utilizado para o projeto

5.Procedimento/Descrição

1. Pesquisa sobre o tema;

1.1 Objetivo

1.2 Enquadramento

1.3 Metodologia utilizada

2. Informações de cada módulo individualmente;

2.1 Funcionamento do módulo

2.2 Descrição

2.3 Especificações

2.4 Funcionamento dos pinos

2.5 Montagem do modulo e materiais a utilizar (resistências e fios de ligação)

3. Montagem do circuito;

3.1 Introdução na placa branca

3.1.1 Foto-díodos

3.1.2 Ultrassom

3.1.3 Comando

3.2 Verificação de falta de materiais para o funcionamento (Resistências para os circuitos dos foto-díodos)

4. Juntar os códigos de cada módulo e criar um só código;

4.1 Foto-díodos

4.2 Ultrassom

4.3 Comando

6. Verificação do desempenho do projeto;

6.1 Teste de código

6.2 Teste de funcionamento dos módulos (fotodíodos, ultrassom e comando);

6.Resultados

Apesar de termos conseguido que o robot tivesse o comportamento proposto/esperado, tais como desviar de objetos, seguir fonte luz ou obedecer a comandos emitidos por um comando IR, devido ao pouco tempo que tivemos para manusear o robô, na demostração não conseguimos mostrar o pretendido como por ex. a função implementada que permite com o mesmo botão, parar o robô e voltar a arrancar, quando está em modo detetar obstáculos ou procura de luz.

Quanto à solução hardware, ficamos bastante satisfeitos com o resultado (placa, disposição componentes e soldaduras).

7.Conclusões

Com este projeto foi possível adquirir conhecimentos tanto a nível do hardware como de software, montar um circuito que engloba vários componentes bem como progredir como estudantes, pois durante a realização deste projeto apareceram vários problemas que obrigou a correção destes mesmos. Conseguimos também consolidar conceitos teóricos que estavam menos aprofundados.

Os resultados comprovam também a eficácia do trabalho, pois estão de acordo com a teoria que foi estudada primeiramente.

Assim, é possível de afirmar que este projeto cumpriu quase todas as especificações e os requisitos definidos à partida com o uso dos módulos propostos no guião dos projetos.

8.Webgrafia e Bibliografia:

Quase toda a informação usada para a realização deste projeto foi retirada do guião dos projetos disponibilizado bem como a informação que aprendemos em sala de aula nas aulas ao longo do semestre.

https://pt.wikipedia.org/wiki/Sensor_de_dist%C3%A2ncia : Site relativo ao sensor de distância.

https://pt.wikipedia.org/wiki/Fotodiodo :Site relativo ao foto-díodo.

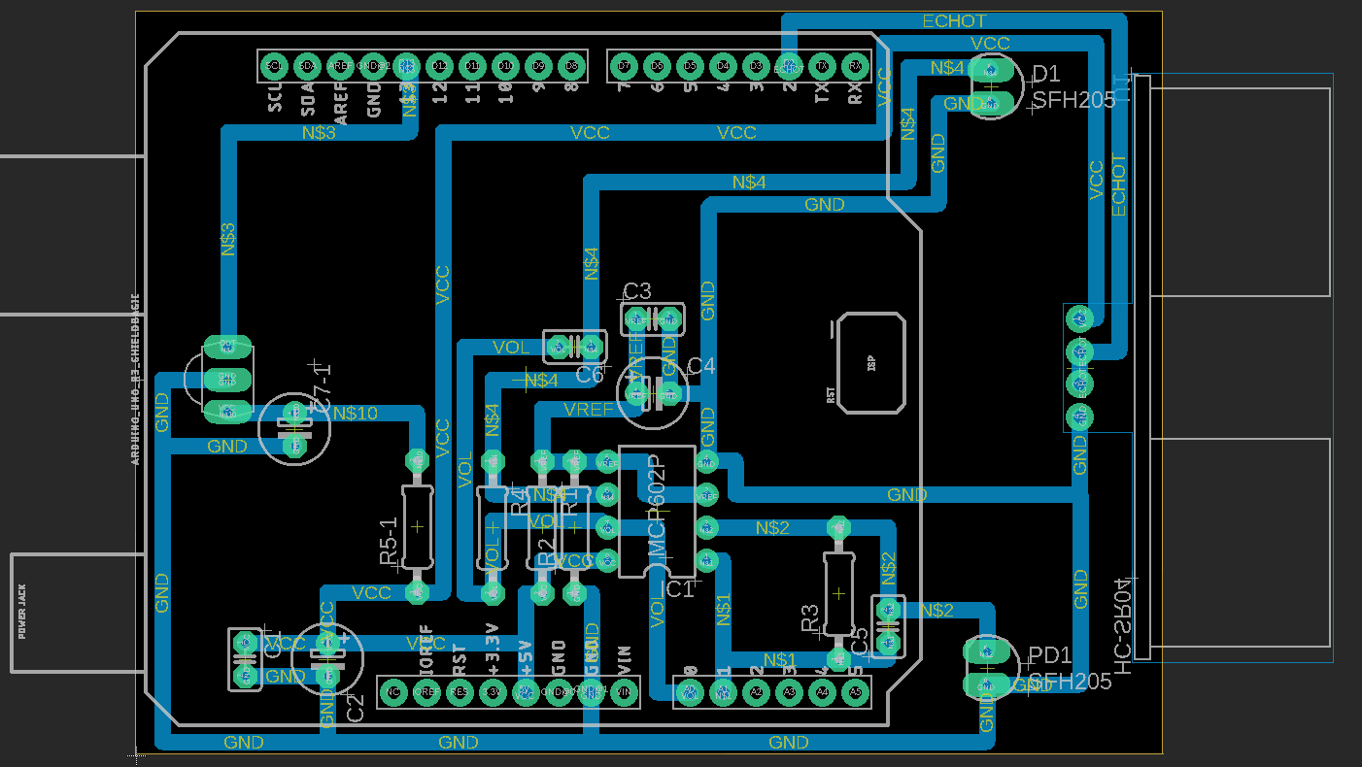
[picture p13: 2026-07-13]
Images/Schematic/Routing.png

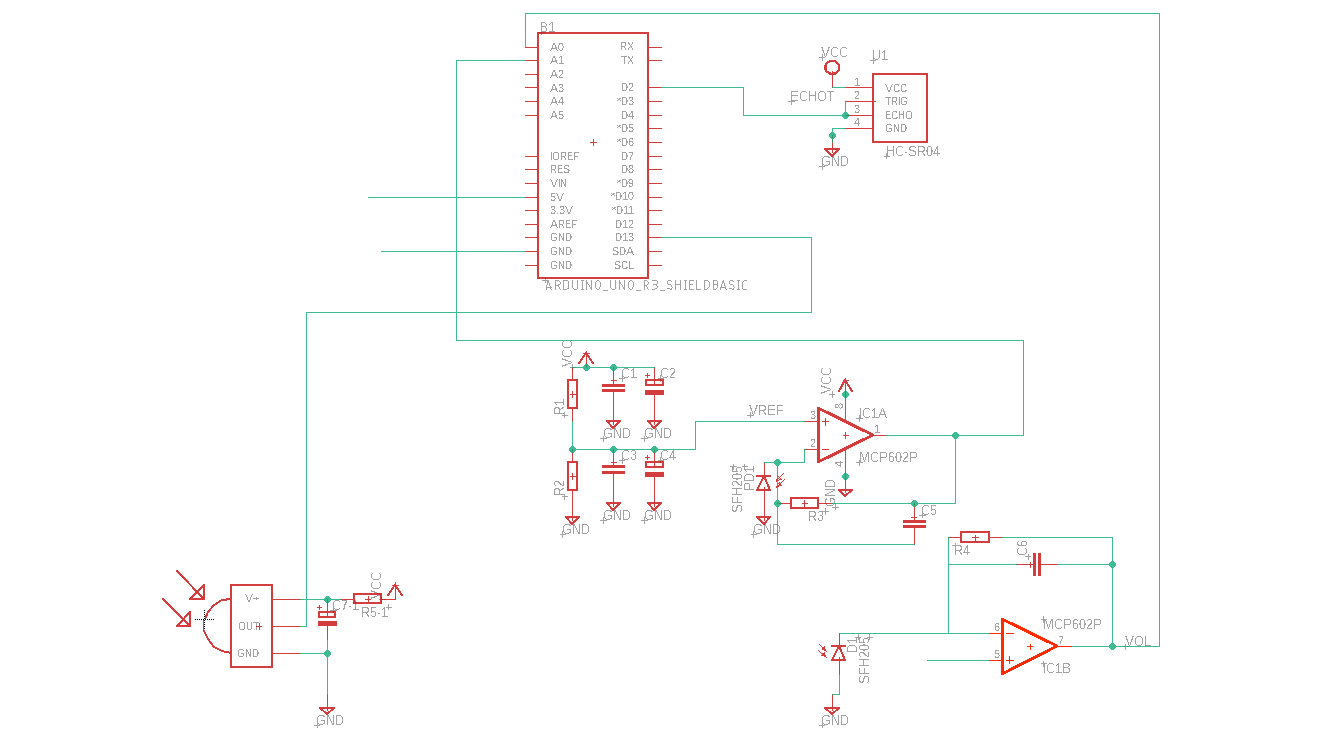
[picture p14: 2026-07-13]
Images/Schematic/Schematic.png

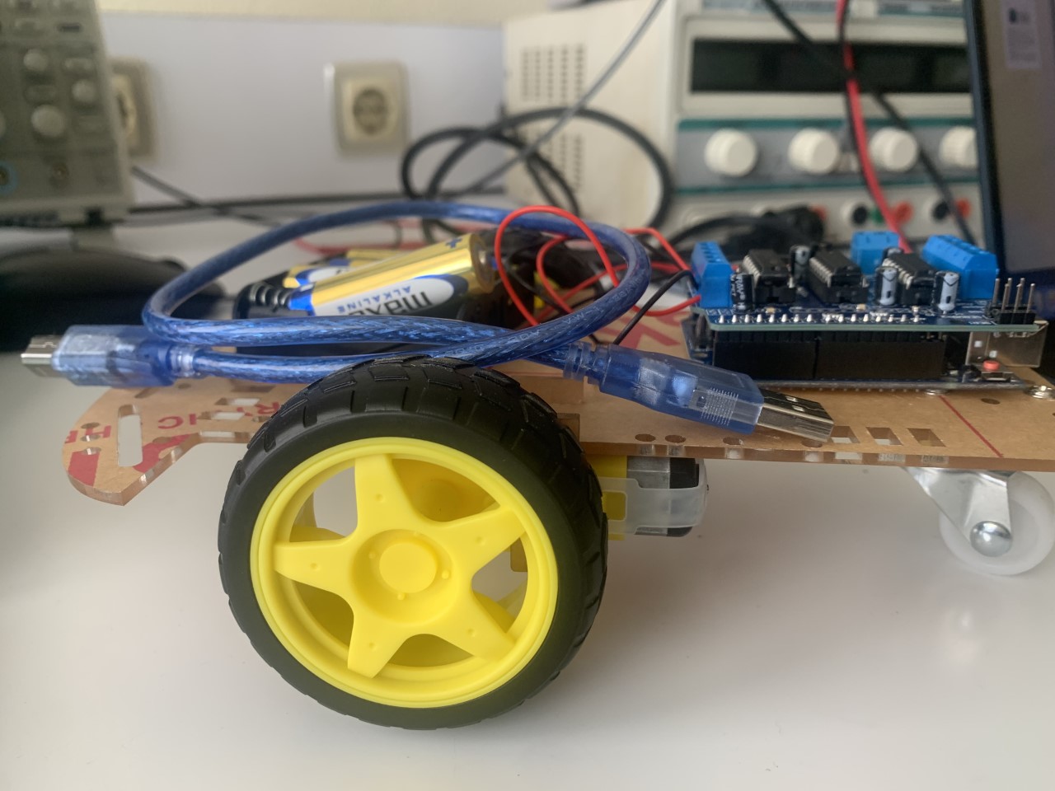
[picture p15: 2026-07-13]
Images/Robot/Robo_2.jpg

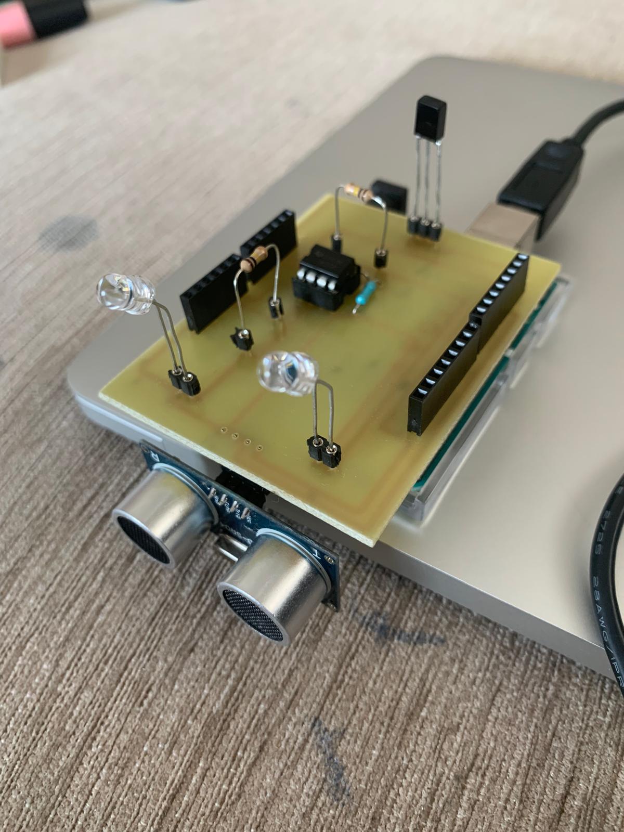
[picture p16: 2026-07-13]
Images/PCB/PCB.jpg

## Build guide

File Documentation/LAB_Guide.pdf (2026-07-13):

41989 – Laboratório de Eletrónica | Guião de Trabalho Prático

## Programação do Robô LabE-Bot com Arduino

Objetivos

- Desenvolver e testar um conjunto de exercícios de programação para o robô usando a

plataforma Arduino

- Criar uma biblioteca de funções LabE.h para o controlo do robô

Enquadramento

O robô móvel LabE-Bot (Fig. 1-a) recorre a uma base de acrílico sobre a qual estão acoplados 2

motores DC e uma roda livre. O Arduino Uno R3 é a unidade inteligente e programável usada para

a leitura de informação sensorial e para comandar os atuadores. Os motores DC são controlados

pela placa de expansão Motor Shield L293D que requer a instalação da biblioteca Adafruit Motor

Shield para Arduino (AFMotor.h).

Neste trabalho, pretende-se usar o cabo USB para alimentar o Arduino, enquanto a placa de

controlo dos motores é alimentada a partir do exterior por pilhas/baterias. O acesso às portas

analógicas/digitais poderá ser feito através do próprio shield L293D. Tal como ilustra a Fig.1-b,

este shield permite o acesso às portas analógicas A0 a A5, bem como aos sinais +5V e Gnd.

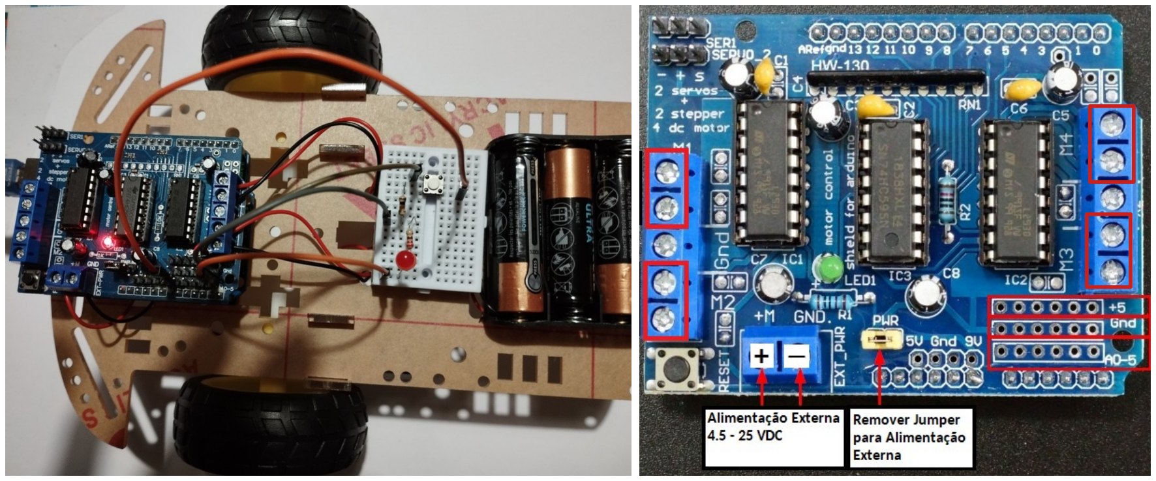
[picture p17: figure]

Fig. 1: (a) Robô móvel LabE-Bot (esquerda); (b) Motor Shield L293D (direita).

Exercícios de Programação em C

1. Comece por usar apenas a placa Arduino alimentada a partir do cabo USB. Crie um programa

que, de cinco em cinco a segundos, escreva no ecrã há quanto tempo está a correr:

A funcionar há 5s

A funcionar há 10s

41989 – Laboratório de Eletrónica | Guião de Trabalho Prático

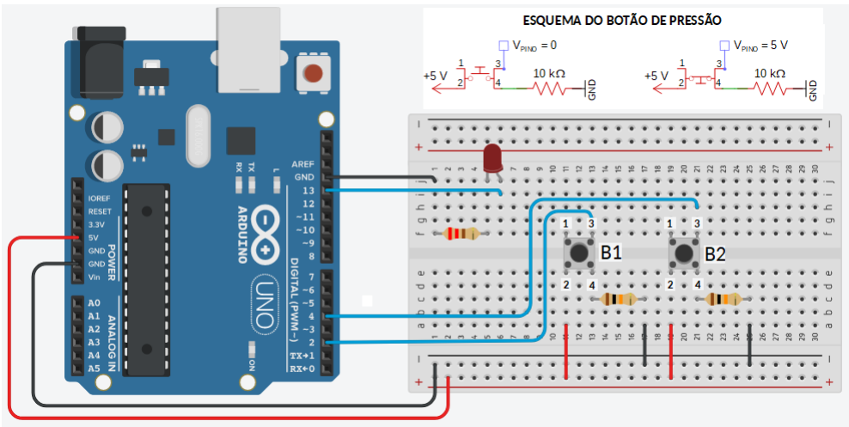
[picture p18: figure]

Fig. 2: Esquema de ligação de um LED e dois botões de pressão ao Arduino.

2. Crie um programa que, quando se carrega num botão de pressão, acende um LED à sua

escolha (ver ligações da Fig. 2). O LED só está aceso enquanto se estiver a carregar no botão

e apaga-se quando se larga o botão.

3. Crie um programa que utiliza dois botões de pressão (“START” e “STOP”) para apagar e

acender um LED: o LED acende quando se carrega no botão “START” (mantendo-se aceso

depois de largar o botão) e apaga quando se carrega no botão “STOP”.

4. Crie um programa que utilize o botão de “START” para selecionar qual de 3 LEDs acender: à

primeira pressão no botão, LED aceso de cada vez; ao chegar ao final, volta ao primeiro).

Adicione o código para apagar o LED que estiver aceso usando o botão de “STOP” (vermelho).

5. Proceda à montagem do Motor Shield L293D alimentado a partir do conjunto de pilhas

disponibilizado. Crie um programa que coloque o robô a fazer movimentos de rotação,

alternadamente, para a direita e para a esquerda. O robô deve rodar para a esquerda, parar,

rodar para a direita, parar, rodar novamente para a esquerda, ... Os movimentos e a paragem

devem ser claramente visíveis.

6. Crie um programa em que o robô inicia um movimenta para a frente, para e regressar ao ponto

de partida. O robô usado requer um procedimento de calibração das rodas?

7. Crie um programa em que o robô deve percorrer os lados de um quadrado, parando quando

volta ao ponto de partida.

8. Crie um programa que reúne as especificações dos movimentos pedidos nos três exercícios

anteriores: rotação alternadas, movimentos para a frente e percuso fechado. O robô deve ficar

parado até se carregar no botão START. O robô indica qual o movimento selecionado através

de um dos LEDs (Led1 a Led3). A seleção do movimento é feita carregando no botão STOP

quando o robô está parado: a cada pressão, é selecionado o movimento seguinte.

9. Crie a biblioteca LabE.h que define as funções e as estruturas de dados para facilitar a programação do robô (e.g., comandar os motores do robô, alterar a velocidade das rodas, etc).
41989_LE_GuiãoTrabalho_LabEBot_2022_23.odt | 2

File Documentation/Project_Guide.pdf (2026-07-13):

41989 – Laboratório de Eletrónica | Guião do Projeto
41989_LE_GuiaProjetos_2022_23 | 1

# GUIÃO DO PROJETO

### LABORATÓRIO DE ELETRÓNICA (41989)

Ano letivo 2022-23

Índice

### 1 INTRODUÇÃO

O projeto de Laboratório de Eletrónica visa o desenvolvimento de um sistema eletrónico envolvendo três componentes principais: sensores, plataforma Arduino e robô móvel. O trabalho tem como objetivo a consolidação e aplicação dos conhecimentos adquiridos, bem como a criação de métodos de trabalho e organização. Em termos gerais, pretende-se controlar o comportamento do robô com recurso a diversos sensores e adotando a plataforma Arduino como unidade inteligente e programável. Em primeiro lugar, pretende-se desenvolver um sensor de luminosidade, baseado em fotodíodos, que permita ao robô detetar e seguir uma fonte luminosa. Em segundo lugar, pretende-se usar um sensor capaz de medir distâncias, baseado em ultrassons, para dotar o robô de capacidade para detetar e evitar obstáculos presentes no ambiente. Finalmente, pretende-se interagir com o robô através de um comando remoto por infravermelhos. O trabalho proposto pressupõe a integração dos diversos módulos hardware e a programação do robô móvel tendo em vista o controlo dos seus movimentos de forma versátil e segura. Neste enquadramento, as próximas secções descrevem as principais capacidades a implementar no robô, bem como as etapas de desenvolvimento a cumprir pelos grupos.

41989 – Laboratório de Eletrónica | Guião do Projeto

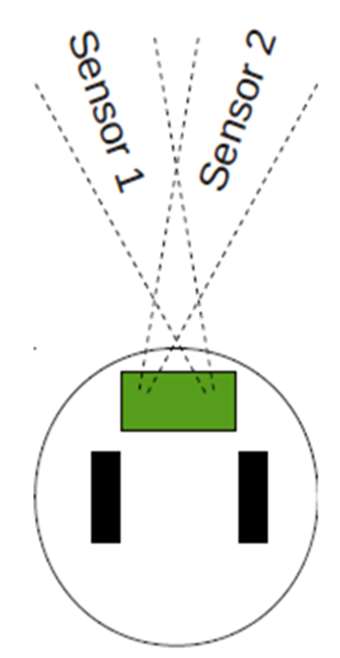
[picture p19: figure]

41989_LE_GuiaProjetos_2022_23 | 2

### 2 DETEÇÃO E SEGUIMENTO DE FONTE LUMINOSA

Esta secção descreve o princípio de funcionamento de um sensor baseado em fotodíodos e o circuito proposto para a implementação do sensor de luminosidade. Este sensor deverá permitir dotar o robô de capacidade para detetar uma fonte luminosa, deslocar-se na sua direção e segui-la à medida que esta se afasta.

### 2.1 Princípio de funcionamento

O funcionamento do sensor de luminosidade baseia-se no facto da corrente num foto-díodo inversamente polarizado ser proporcional à intensidade luminosa que atinge a sua área sensível, permitindo a transdução da intensidade luminosa numa grandeza elétrica. O sensor a desenvolver será constituído por dois fotodíodos e respetivos circuitos de leitura. Os foto-díodos devem ser montados de forma que o seu “cone de visibilidade” esteja orientado conforme ilustra a Fig. 1: ambos virados para a frente do robô, estando um ligeiramente orientado para a direita e o outro ligeiramente orientado para a esquerda.

Fig. 1: Montagem dos sensores no robô.

Os dois foto-díodos serão utilizados para proporcionar uma navegação reativa do robô de acordo com o seguinte algoritmo:
- Se um dos circuitos do sensor detetar uma intensidade luminosa maior que o outro circuito, isso significa que a fonte de luz se encontra à frente do robô, mas desviado para o lado visto por esse foto-díodo. Nesse caso, o robô deverá orientar-se para o lado onde está a luz (e.g., rodando).
- Se os dois circuitos detetarem uma intensidade luminosa semelhante, a fonte de luz estará à frente do robô, sendo vista de forma idêntica pelos dois foto-díodos. Neste caso, o robô deverá andar em frente.
- Se nenhum dos foto-díodos detetar a fonte luminosa, o robô deverá procurar essa fonte. Nesse caso, poderá rodar sobre si próprio, andar em frente ou até mover-se de forma aleatória.

41989 – Laboratório de Eletrónica | Guião do Projeto

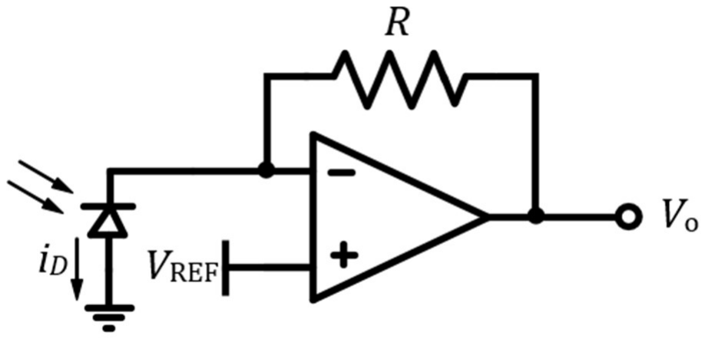
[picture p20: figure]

41989_LE_GuiaProjetos_2022_23 | 3

### 2.2 Descrição do circuito

O circuito básico a implementar é baseado no foto-díodo SFH213 [1] e no amplificador operacional “rail-to-rail” MCP601 [2]. Pela análise do circuito da Fig. 2, a corrente que percorre o foto-díodo irá atravessar a resistência R, pelo que a tensão V à saída do AmpOp será dada por V = V + Ri. O conjunto formado pelo AmpOp e pela resistência funciona como um amplificador de transimpedância, i.e., converte uma corrente de entrada numa tensão de saída.

Fig. 2: Circuito básico do sensor de luminosidade.

A Fig. 3 apresenta uma proposta para o circuito completo a implementar. Como as saídas do circuito (V e V) devem ser ligadas a duas entradas analógicas disponíveis na placa Arduino, a sua variação terá de estar compreendida entre os 0 e os 5 V. Assim sendo, a escolha de VREF, R3 e R4 será de particular importância e deverá ser feita por cada um dos grupos durante a implementação do circuito em placa branca. Os condensadores C e C visam providenciar estabilidade aos amplificadores (evitar oscilações indesejadas). A função de C e C (e C e C) é mitigar flutuações na alimentação de IC1 a altas e baixas frequências, respetivamente.

A tensão V é uma referência responsável por garantir que o foto-díodo se encontra inversamente polarizado e, por isso, a sua escolha deverá ter em conta esse facto. Para além disso, existe um compromisso pois quanto maior for o seu valor, menor será a gama de tensão disponível à saída. Assim sendo, como os valores máximo e mínimo da tensão de saída (V e V) serão 5 V e V, respetivamente, as resistências (R e R) do ponto de vista teórico deverão ser calculadas através da expressão (V − V)⁄i, em que i é a corrente máxima fornecida pelo foto-díodo. Finalmente, o uso de uma alimentação simples requer a criação de uma tensão de referência intermédia que é obtida através de um divisor de tensão formado por R e R.

41989 – Laboratório de Eletrónica | Guião do Projeto

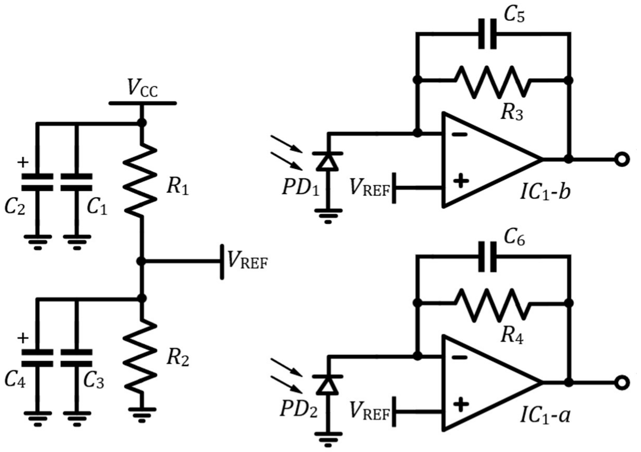
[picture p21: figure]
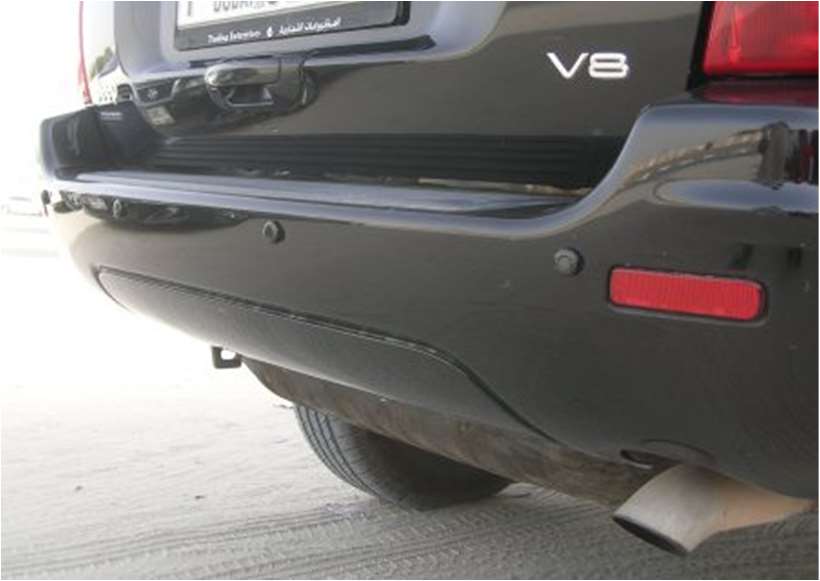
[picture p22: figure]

41989_LE_GuiaProjetos_2022_23 | 4

Fig. 3: Esquemático completo do circuito sensor de luz.

Lista de componentes:
PD1, PD2 | SFH213
IC1-a, IC1-b | MCP601
R1, R2, R3, R4
C1, C3 | 100 nF
C2, C4 | 10 μF
C5, C6 | 4.7 pF

### 3 DETEÇÃO DE OBSTÁCULOS POR ULTRASSONS

Os ultrassons são ondas sonoras (oscilações mecânicas que se propagam no ar) a uma frequência superior à frequência máxima que o ouvido humano consegue detetar (em geral, considera-se que o limite superior em frequência da audição humana é de 20 kHz). Em muitas aplicações, é necessária a medição da distância a um objeto, quer para estimar um comprimento como para detetar a presença de objetos ou obstáculos. Os sensores de ultrassons constituem uma solução económica para estes fins, tanto para a medida de comprimentos, que se encontra, por exemplo, nalgumas balanças que medem a altura para determinar o índice de massa corporal (relação entre peso e altura de uma pessoa), como para a deteção de obstáculos, como é o caso dos chamados sensores de estacionamento instalados na dianteira e traseira dos automóveis (Fig. 4).

Fig. 4: Sensores de estacionamento.

41989 – Laboratório de Eletrónica | Guião do Projeto

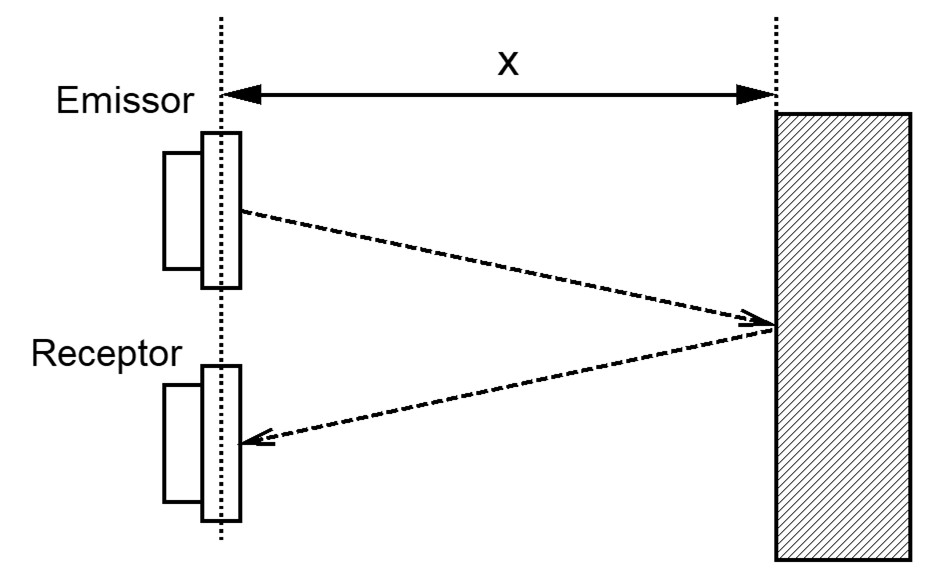
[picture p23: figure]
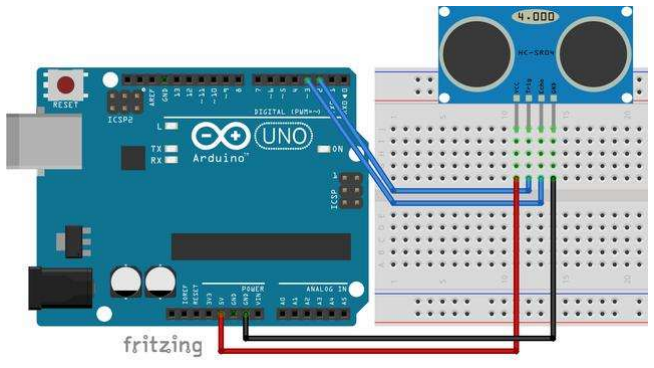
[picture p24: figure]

41989_LE_GuiaProjetos_2022_23 | 5

A medição de distâncias por ultrassons baseia-se na emissão de uma sequência de impulsos e na subsequente leitura do eco. O tempo decorrido entre a emissão do sinal e a receção do correspondente eco está relacionado com a distância ao objeto que causou o eco. Considerando a situação da Fig. 5, a distância x está relacionada com o tempo t

que demora a chegar o eco por:

x =

tv | (1)
em que v é a velocidade de propagação do som no ar.

Assim, se um sistema emitir uma sequência de impulsos ultrassónicos, o tempo que demora a receber o seu eco é uma medida da distância ao objeto onde o som é refletido. A velocidade v a que o som se propaga no ar, em metros por segundo, é dada, de forma aproximada, por:

v = 20.06√Θ | (2)
em que Θ é a temperatura do ar em Kelvin.

Fig. 5: Medição de distâncias por ultrassons.

Tendo por base estes princípios, o trabalho proposto visa a utilização do sensor de distância HC-SR04
[3] para permitir ao robô móvel detetar e evitar obstáculos que surjam no seu caminho (ver Fig. 6). Este sensor utiliza um emissor e um recetor de ultrassons separados: o sinal a emitir consistirá numa curta sequência de ultrassons, após a qual o emissor se silenciará, ficando o sistema à espera da chegada do eco.

Fig. 6: Sensor de distâncias ultrassónico HC-SR04 (esquerda) e exemplo de ligação ao Arduino (direita).

41989 – Laboratório de Eletrónica | Guião do Projeto
41989_LE_GuiaProjetos_2022_23 | 6

### 4 COMANDO REMOTO POR INFRAVERMELHOS

Um dos objetivos do trabalho proposto é desenvolver um módulo de interação entre o utilizador humano e o robô usando um comando remoto por infravermelhos (IV). Esta é uma forma simples de transferência de dados sem fios. O comando recorre a um LED para a emissão de luz infravermelha, enquanto usa um circuito de descodificação na receção desse sinal pelo aparelho comandado. Para poder distinguir as várias funções, cada tecla tem associado um código que é enviado através da ligação de infravermelhos. Existem vários tipos de protocolos usados em telecomandos IV, sendo os mais comuns o RC-5 Remote Protocol e o NEC Remote Protocol. Esta secção descreve o princípio de funcionamento dos comandos IV e o circuito de descodificação a usar no projeto.

### 4.1 Princípio de funcionamento

A primeira coisa a ter em atenção é que o sinal de IV enviado pelo telecomando não é um feixe simples de infravermelhos: a luz enviada é modulada a 38 kHz. Isto significa que o sinal não está permanente ligado, mas é constantemente ligado e desligado, a uma frequência de 38 kHz (ou seja, 38.000 vezes por segundo). Referindo-nos à Fig. 7, uma sequência de “ligado/desligado” como a do lado esquerdo é transmitida como se indica do lado direito. O LED emissor, quando “ligado”, é, na realidade, ligado e desligado (“comutado”) a 38 kHz. Este esquema de transmissão é, obviamente, mais complexo do que simplesmente ligar e desligar o LED. Porque se usa, então? A resposta tem a ver com a imunidade ao ruído.

Fig. 7: Emissão de luz infravermelha pelo telecomando.

Os infravermelhos podem ser emitidos por um conjunto grande de fontes; por exemplo, a luz solar inclui radiação infravermelha no seu espectro. Assim, o IV detetado pelo recetor pode provir tanto do telecomando, como de um outro emissor. Se a transmissão não fosse modulada (ou, usando terminologia das telecomunicações, se a transmissão fosse em banda base), era possível que os IV gerados por outras fontes fossem lidos e interpretados pelo recetor, dando origem a situações indesejadas. Com a modulação, o recetor só se preocupa com sinais que estejam modulados a 38 kHz; todos os outros são ignorados, tornando o sistema mais imune ao ruído. A transmissão do código pelo telecomando, que corresponde a uma sequência de “uns” e “zeros”, tem uma outra sofisticação. Um “1” é transmitido com uma sequência “ligado/desligado” e o “0” como uma sequência “desligado/ligado”. Esta forma de codificação é chamada um “código de Manchester” e gera sequências como a da Fig. 8, garantindo a existência de transições no sinal recebido que facilitam a descodificação pelo recetor.

41989 – Laboratório de Eletrónica | Guião do Projeto

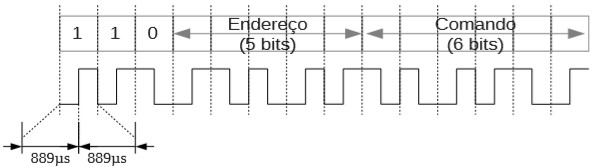
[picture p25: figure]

41989_LE_GuiaProjetos_2022_23 | 7

Fig. 8: Codificação dos valores “1” e “0” (à esquerda) e um exemplo de codificação de uma sequência de bits (à direita).

No protocolo RC-5, os dados são transmitidos numa trama de 14 bits, sendo a duração de cada bit de 2x889 µs [2]. Tal como representado na Fig. 9, esta trama é constituída por:

- Sequência inicial “110”;
- 5 bits de endereço, que definem o equipamento a ser controlado; e
- 6 bits para o comando.

Fig. 9: Trama RC-5 de 14-bits.

### 4.2 Protocolo de comunicação NEC

Os comandos IV disponibilizados para o projeto usam o protocolo NEC (NEC Remote Protocol) baseado numa codificação de dados diferente, designada por “Pulse Distance Encoding” [5]. Por um lado, o “0” lógico é transmitido como uma sequência de impulsos “ligado/desligado” com duração de 562.5 µs, seguido de “desligado” pelo mesmo período, resultando numa num tempo total de 1125 µs. Por outro lado, o “1” lógico é transmitido como um trem de impulsos “ligado/desligado” com duração de 562.5 µs, seguido de “desligado” por um período de 1687 µs (3x 562.5 µs), com um tempo total de transmissão de 2250 µs.

A Fig. 10 mostra um exemplo dos dados transmitidos usando o protocolo NEC com a indicação dos vários campos da mensagem e a sua ordem:

- Sequência inicial com duração de 9 ms (16x 562.5 µs) seguido de um pulso invertido de 4.5 ms;
- 8 bits de endereço (definem o equipamento a ser controlado) seguido dos bits invertidos;
- 8 bits para o comando seguido dos bits invertidos.

41989 – Laboratório de Eletrónica | Guião do Projeto

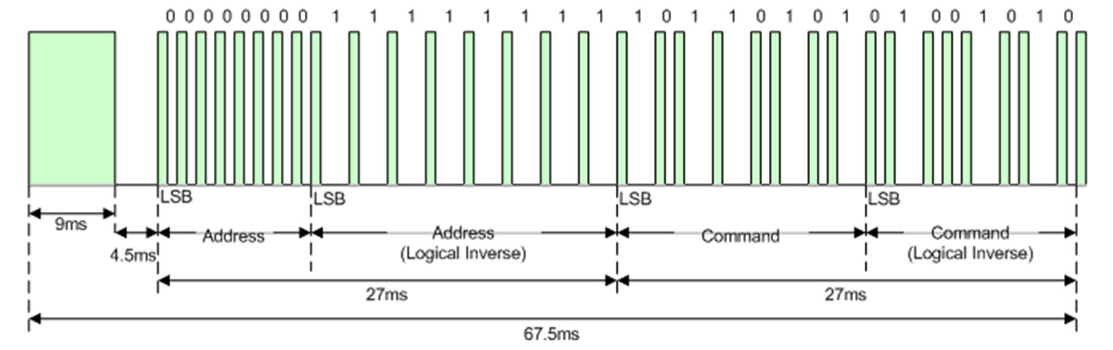
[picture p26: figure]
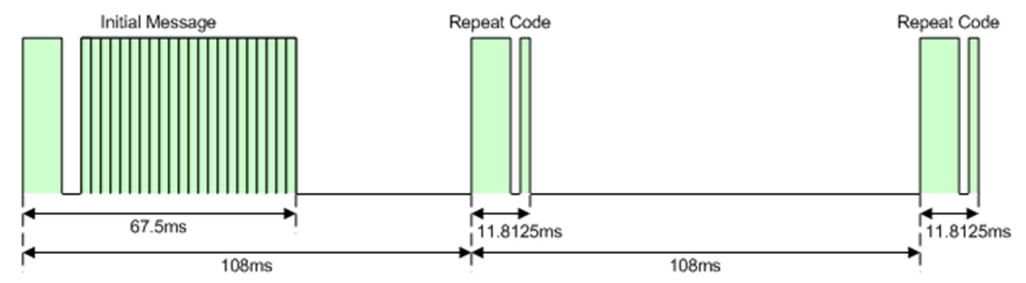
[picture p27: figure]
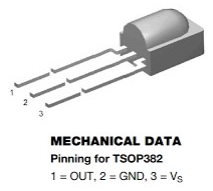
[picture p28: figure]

41989_LE_GuiaProjetos_2022_23 | 8

Fig. 10: Exemplo de uma trama usando o protocolo NEC.

Desta forma, são necessários 27 ms para transmitir quer os 16 bits do endereço como para transmitir os 16 bits do comando e 67.5 ms para a transmissão completa da mensagem. No caso de se manter uma tecla premida, é gerado um código repetido de acordo com a Fig. 11 que consiste em:

- Sequência inicial com duração de 9 ms seguido de um pulso invertido de 2.25 ms;
- 8 bits de endereço (definem equipamento a ser controlado) e os correspondentes 8 bits invertidos;
- Um trem de impulsos de duração 562.5 µs.

Fig. 11: Exemplo da transmissão do código repetido após o envio de uma mensagem inicial.

### 4.3 Circuito de descodificação usando recetor TSOP

O circuito associado ao comando remoto por infravermelhos será baseado no recetor TSOP582 da Vishay
[6] que faz a descodificação do sinal recebido. Este circuito integrado incorpora um foto-díodo recetor e um circuito de deteção, sintonizado para a frequência de modulação, o que lhes
confere a propriedade de serem sensíveis apenas a infravermelhos modulados
numa frequência específica. O circuito integrado TSOP582 gera um sinal digital
na saída (OUT) que poderá ser lido por um microcontrolador. A Fig. 12 ilustra o circuito de ligação do TSOP à plataforma Arduino.

41989 – Laboratório de Eletrónica | Guião do Projeto

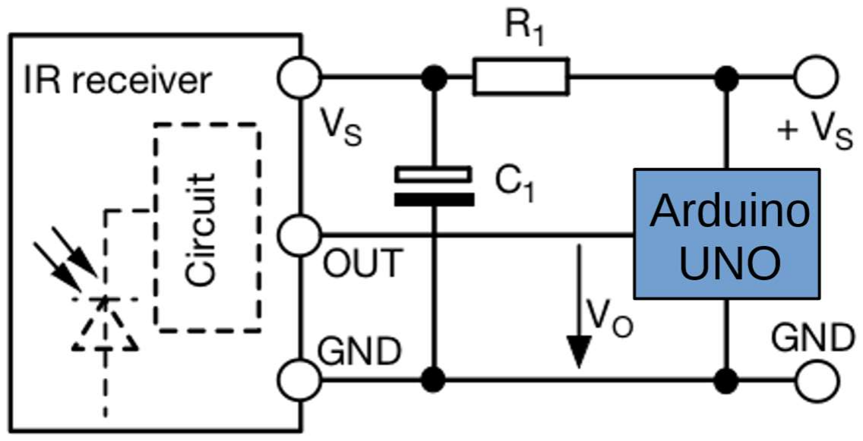
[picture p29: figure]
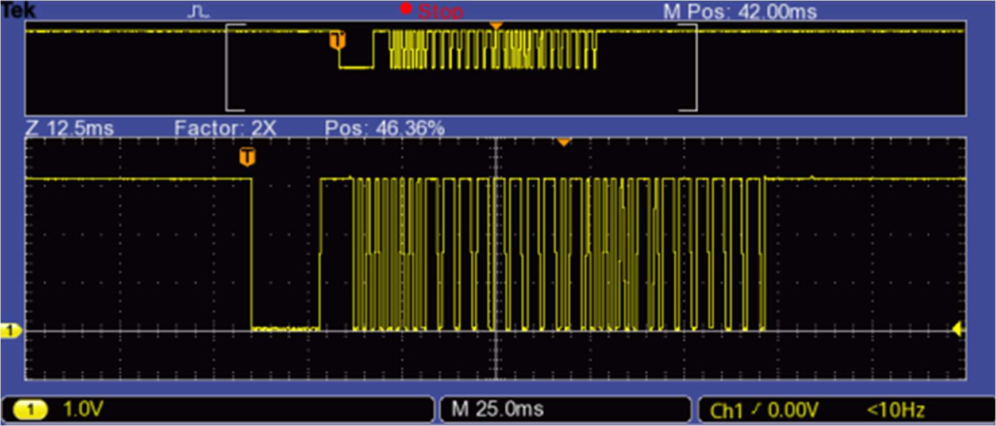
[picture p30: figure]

41989_LE_GuiaProjetos_2022_23 | 9

Fig. 12: Ligação do circuito recetor TSOP582 à plataforma Arduino.

A Fig. 13 mostra um exemplo da forma do sinal observado no osciloscópio quando é premido um botão do comando remoto.

Fig. 13: Sinal obtido na saída do TSOP582.

### 5 ETAPAS DE DESENVOLVIMENTO

Esta secção descreve as etapas de desenvolvimento a cumprir pelos grupos e que devem ser percorridas sequencialmente: (1) projeto do circuito impresso, (2) montagem e teste dos circuitos em placa branca, e
(3) programação do comportamento do robô.

### 5.1 Projeto da placa de circuito impresso

A primeira etapa do trabalho está centrada no projeto dos circuitos eletrónicos em placa de circuito impresso usando o software EAGLE. O objetivo é desenvolver um módulo integrado (Shield) que incluía os circuitos eletrónicos propostos – sensor de luminosidade, sensor de ultrassons baseado no HC-SR04 e circuito recetor de infravermelhos baseado no TSOP – que possa ser acoplado diretamente na placa Arduino. A Tabela 1 resume a lista de componentes a utilizar no projeto com indicação dos correspondentes devices/packages no EAGLE.

41989 – Laboratório de Eletrónica | Guião do Projeto
41989_LE_GuiaProjetos_2022_23 | 10
Componente | Device | Package | Descrição
Módulo IV | TSOP4856 | TSOP18xx | Infrared Receiver Module
IC1 | HC-SR04 | | Ultrasonic Range Module
IC2 | MCP601P | DIL08 | Single Op Amp
PD1 e PD2 | SFH213 | SFH205 | PHOTO DIODE
R1, R2, R3 e R4 | R-EU_0207/10 | 0207/10 | RESISTOR, European Symbol
C2 e C4 | CPOL-EUE2.5-6 | E2.5-6 | POLARIZED CAPACITOR, European Symbol
C1, C3, C5 e C6 | C-EU025-025X050 | C025-025X050 | CAPACITOR, European Symbol

Tabela 1: Componentes EAGLE a utilizar no projeto.

O processo de fabrico das placas de circuito impresso (PCB) requer alguns cuidados particulares. Seguem abaixo algumas normas a considerar no projeto dos PCBs:

1. Cada grupo faz o seu circuito tendo como referência as dimensões da placa Arduino 2.70"×2.10" (as dimensões são indicadas em polegadas por ser mais prático usá-las no EAGLE).
2. É da responsabilidade de cada grupo fazer a verificação das regras elétricas (ERC) e de desenho (DRC). As placas não podem voltar a ser produzidas! É preciso fazer bem à primeira vez!
3. Cada grupo deve também verificar que os componentes que estão no projeto do circuito impresso correspondem, em termos de referências e dimensões, aos componentes reais que serão usados. A lista que é indicada em cada trabalho pode sofrer alterações (por exemplo, devido à indisponibilidade de um componente, que pode ter de ser substituído por outro).
4. No desenvolvimento da placa de circuito impresso é preciso considerar pontos de ligação ao exterior que serão concretizados através de fichas/conetores elétricos. Em termos do projeto EAGLE, devem ser usados “headers” (“Pin Header Connectors” da biblioteca “pinheader”).
5. As pistas de cobre têm de ter uma largura adaptadas ao processo de fabrico utilizado no DETI. Ao desenhar uma pista com o comando “Route” deve garantir que a largura é de 0.050” ou superior.
6. Há um ficheiro de configuração (LabE.dru) disponível na página do moodle da disciplina (no tópico “Projetos”) que permite programar automaticamente os parâmetros acima indicados, entre outros.

41989 – Laboratório de Eletrónica | Guião do Projeto
41989_LE_GuiaProjetos_2022_23 | 11

### 5.2 Montagem e teste dos circuitos eletrónicos em placa branca

A segunda etapa do projeto incidirá sobre a montagem e teste, em placa branca, de cada um dos circuitos eletrónicos, incluindo o sensor de distância HC-SR04. Para cada um deles é preciso seguir um conjunto de passos que demonstrem que funcionam como esperado:

1. Sempre que possível, os grupos devem demonstrar que o circuito que desenvolveram se comporta como esperado e que as tensões e correntes geradas no circuito estão de acordo com o fenómeno físico que se pretende detetar.
2. Antes de começar a desenvolver programas para movimentar o robô, os grupos devem demonstrar que têm um sensor a funcionar, com um programa que torna o robô num instrumento de medida, por exemplo, escreve no ecrã a leitura feita da grandeza que está a medir ou o código de cada tecla.
3. Finalmente, deve ser feita a caracterização do sensor como instrumento de medida, comparando valores esperados com valores medidos e determinando os erros associado. No caso concreto do circuito recetor de infravermelhos, os grupos devem avaliar a taxa de sucesso do algoritmo usado para a descodificação do conjunto de teclas selecionadas.

### 5.3 Integração do hardware e programação do robô

A última etapa do trabalho será dedicada à integração dos vários módulos hardware e à programação do robô móvel. Deste modo, o robô deve ser capaz de alterar o seu comportamento em função da informação sensorial recebida em cada momento. Os requisitos e capacidades do robô podem ser sintetizados nos seguintes pontos:
- O comando remoto deve permitir a interação com o robô, permitindo-lhe alterar entre os vários modos de controlo implementados, tais como seguir uma fonte luminosa, evitar obstáculos ou responder às ordens do telecomando (e.g., ordem de “arranque” e “paragem”).
- No modo “seguir fonte de luz”, o robô deve conseguir orientar-se para uma fonte luminosa, deslocar-se na sua direção e segui-la à medida que esta se afasta.
- No modo “evitar obstáculos”, o robô deve conseguir imobilizar-se a uma distância programada de uma parede ou de um objeto suficientemente grande para poder ser detetado pelo sistema de ultrassons; o robô deve, também, conseguir deslocar-se, evitando os objetos que encontre no seu caminho.

41989 – Laboratório de Eletrónica | Guião do Projeto
41989_LE_GuiaProjetos_2022_23 | 12

### REFERÊNCIAS

[1] OSRAM, | “PIN | Photodiode,” | SFH213 | datasheet | [online]. | https://docs.rs-
online.com/f594/0900766b814f568d.pdf [Accessed: 24-03-2023]
[2] Microchip, “MCP601/1R/2/3/4 Rail-to-Rail Input/Output, 2.8 MHz Op Amps,” MCP601 datasheet [online]. 2.7V to 5.5V Single Supply CMOS Op Amp (microchip.com) [accessed: 24-03-2023]
[3] Sparkfun, | “Ultrasonic | Ranging | Module | HC-SR04”, | HC-SR04 | datasheet | [online].
https://cdn.sparkfun.com/datasheets/Sensors/Proximity/HCSR04.pdf [accessed: 24-03-2023]
[4] SB-Projects, “Philips RC-5 Protocol,” [Online]. https://sbprojects.net/knowledge/ir/rc5.php [accessed: 24-03-2023]
[5] SB-Projects, “SB-Projects: IR NEC Protocol,” [Online]. https://www.sbprojects.net/knowledge/ir/nec.php [accessed: 24-03-2023]
[6] Vishay, “Vishay - TSOP582.., TSOP584.., TSOP592.., TSOP594.. - IR Receiver Modules for Remote Control Systems,” TSOP582X datasheet [online]. http://www.vishay.com/docs/82461/tsop582.pdf [accessed: 24-03-2023]

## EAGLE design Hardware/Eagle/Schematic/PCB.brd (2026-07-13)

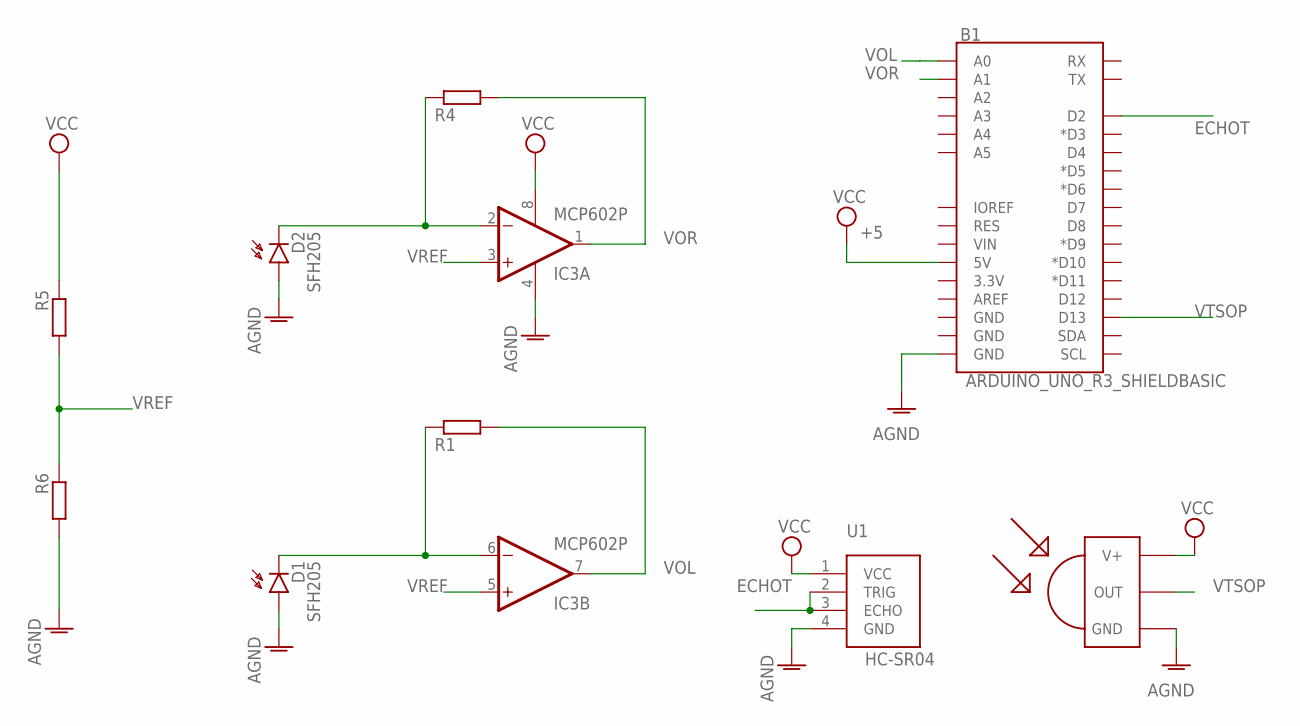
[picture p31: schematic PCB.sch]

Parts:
B1: ARDUINO_UNO_R3_SHIELDBASIC; UNO_R3_SHIELD
D1, D2: SFH205
IC3: MCP602P; DIL08
R1, R4, R5, R6: R-EU_0207/10; 0207/10
U1: HC-SR04; XCVR_HC-SR04
U$3: TSOP4856; TSOP18XX

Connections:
AGND: B1.GND@0 (GND), D1.A, D2.A, IC3.4 (V-), R6.2, U1.4 (GND), U$3.GND
ECHOT: B1.D2, U1.2 (TRIG), U1.3 (ECHO)
unnamed: D2.K (C), IC3.2 (-IN), R4.1
unnamed: D1.K (C), IC3.6 (-IN), R1.1
VCC: B1.5V, IC3.8 (V+), R5.1, U1.1 (VCC), U$3.VCC (V+)
VOL: B1.A0, IC3.7 (OUT), R1.2
VOR: B1.A1, IC3.1 (OUT), R4.2
VREF: IC3.3 (+IN), IC3.5 (+IN), R5.2, R6.1
VTSOP: B1.D13, U$3.OUT

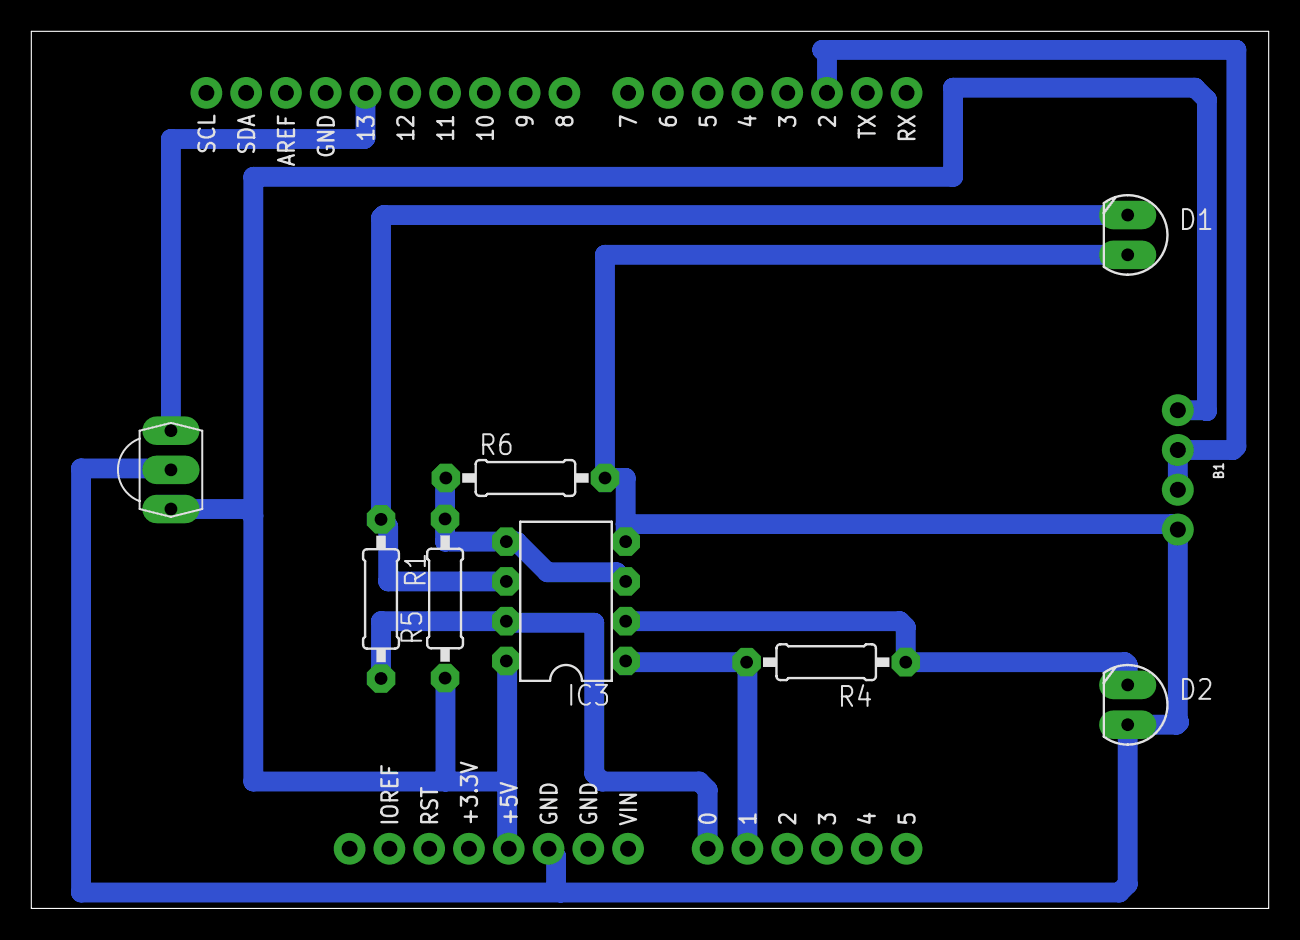
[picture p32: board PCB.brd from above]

Board: 2 copper layers, 79.0 x 56.0 mm, 10 parts (1 on the bottom side), 9 nets.

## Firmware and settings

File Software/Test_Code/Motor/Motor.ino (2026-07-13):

// Definindo os pinos do Motor Shield L293D
int ENA = 10; //Controla a velocidade das rodas conectadas a IN1 e IN2
int IN1 = 9;
int IN2 = 8;
int IN3 = 7;
int IN4 = 6;
int ENB = 10; //Controla a velocidade das rodas conectadas a IN3 e IN4

void setup() {
  pinMode(ENA, OUTPUT);
  pinMode(IN1, OUTPUT);
  pinMode(IN2, OUTPUT);
  pinMode(IN3, OUTPUT);
  pinMode(IN4, OUTPUT);
  pinMode(ENB, OUTPUT);
}

void loop() {
  //Girar para a esquerda
  digitalWrite(IN1, LOW);
  digitalWrite(IN2, HIGH);
  digitalWrite(IN3, LOW);
  digitalWrite(IN4, HIGH);
  analogWrite(ENA, 100);
  //analogWrite(ENB, 100);
  delay(1000); 

  // Parar
  digitalWrite(IN1, LOW);
  digitalWrite(IN2, LOW);
  digitalWrite(IN3, LOW);
  digitalWrite(IN4, LOW);
  analogWrite(ENA, 0);
  //analogWrite(ENB, 0);
  delay(1000); 

  //Girar para a direita
  digitalWrite(IN1, HIGH);
  digitalWrite(IN2, LOW);
  digitalWrite(IN3, HIGH);
  digitalWrite(IN4, LOW);
  analogWrite(ENA, 100);
  //analogWrite(ENB, 100);
  delay(1000); 

  // Parar
  digitalWrite(IN1, LOW);
  digitalWrite(IN2, LOW);
  digitalWrite(IN3, LOW);
  digitalWrite(IN4, LOW);
  analogWrite(ENA, 0);
  //analogWrite(ENB, 0);
  delay(1000); 
}

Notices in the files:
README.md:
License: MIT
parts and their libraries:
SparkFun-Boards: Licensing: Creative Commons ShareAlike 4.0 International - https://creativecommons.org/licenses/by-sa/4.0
